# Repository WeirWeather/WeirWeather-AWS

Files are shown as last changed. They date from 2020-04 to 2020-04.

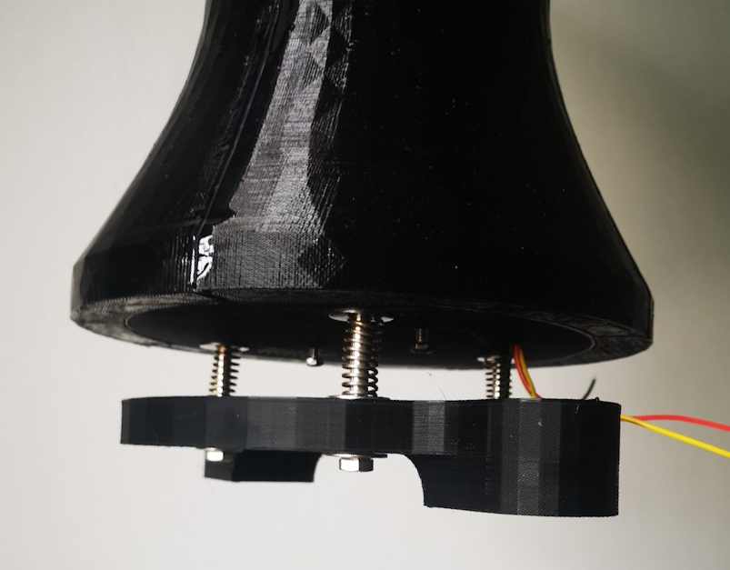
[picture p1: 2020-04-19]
hardware/Rain Gauge/Photos/Support.png

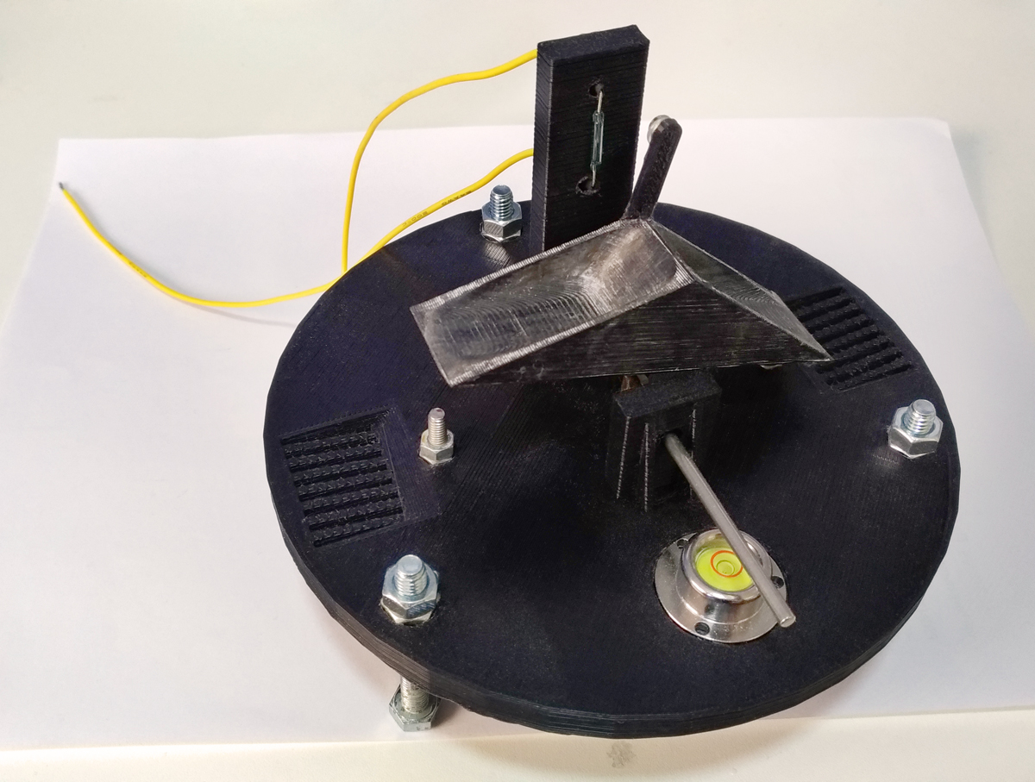
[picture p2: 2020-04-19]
hardware/Rain Gauge/Photos/Prototype Base.jpg

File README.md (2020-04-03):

# WeirWeather

This repository is for the WeirWeather Automatic Weather Station project which provides live weather measurements from the James Weir buidling in Glasgow, co-ordinates: [55.862809, -4.245339]. This repository contains all of the software, CAD models, BOMs and EAGLE PCB files required to reproduce the weather station and the website.

This project was completed for a Masters group project at the University of Strathclyde Electrical & Electronic Engineering Department. 

WeirWeather - 

- Callum Brooksby
- Zack North
- Mario Manca
- Alexander Ulrichsen
- Tesfu Gebremedhin

88040462_648263302590816_2950428286498373632_n

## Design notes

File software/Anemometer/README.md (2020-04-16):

# Anemometer Code

## Files
The `Anemometer/` folder contains the corresponding `.ino` file. The code is intended for an ATtiny85 which was programmed through the Arduino IDE.

## Code Key Points
 - Calculate velocity in m/s based on anemometer radius and number of pulses per revolution
 - Average function
 - Debouncing functionality
 - Send data to master on request

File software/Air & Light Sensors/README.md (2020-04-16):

# LDR Code

## Files
The `LDR/` folder contains the corresponding `.ino` file. The code is intended for an ATtiny85 which was programmed through the Arduino IDE.

## Code Key Points
 - Check when the selected pin is high or low (i.e. day or night)
 - Averaging function
 - Send data to master on request

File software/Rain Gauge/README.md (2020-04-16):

# Rain Gauge Code

## Files
The `Rain_Gauge/` folder contains the corresponding `.ino` file. The code is intended for an ATtiny85 which was programmed through the Arduino IDE.

## Code Key Points
 - Read when the reed switch is triggered using an interrupt
 - Debouncing functionality to minimise false readings
 - Evaluate the amount of rain fallen per day in mm
 - Evaluate the rain intensity in mm/h
 - Averaging function for better results
 - Send data to master on request

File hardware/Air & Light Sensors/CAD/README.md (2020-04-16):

# Radiation Shield CAD Files
The radiation shield in this project is an adaptation based on the work of micromet on the designed named "Radiation Shield For Weather Station Temperature/Humidity" which can be found at: https://www.thingiverse.com/thing:1067700

 - `Support.dwg` is the custom support designed to adapted the radiation shield to our AWS
 - `PCB Holder.dwg` is the custom PCB holder designed to sustain the four atmospheric sensors
 - The `STLs/` folder contains the single .stl files as they were 3D-printed

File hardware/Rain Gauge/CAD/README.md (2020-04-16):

# Rain Gauge CAD Files

 - `Rain_Gauge.dwg` is the complete rai gauge CAD drawing, containing base, collector, funnel, PCB enclosure, and support.
 - The `STLs/` folder contains the single .stl files as they were 3D-printed

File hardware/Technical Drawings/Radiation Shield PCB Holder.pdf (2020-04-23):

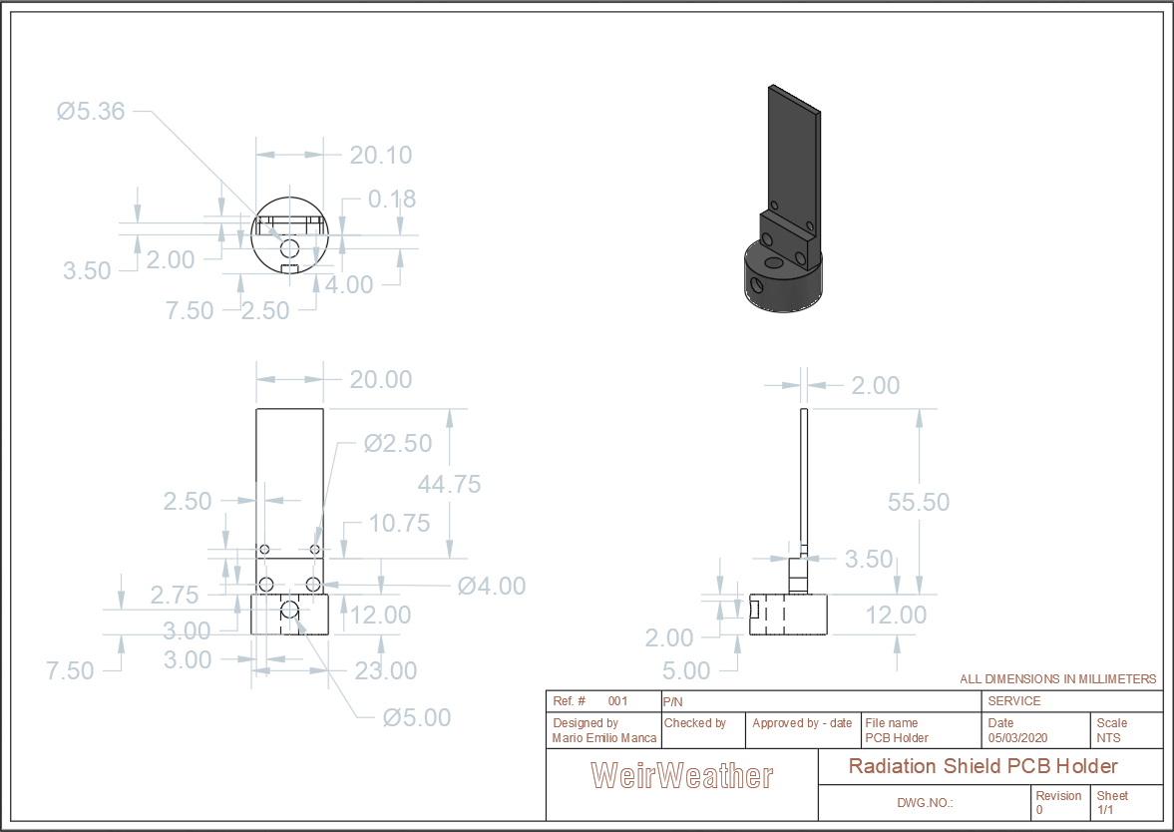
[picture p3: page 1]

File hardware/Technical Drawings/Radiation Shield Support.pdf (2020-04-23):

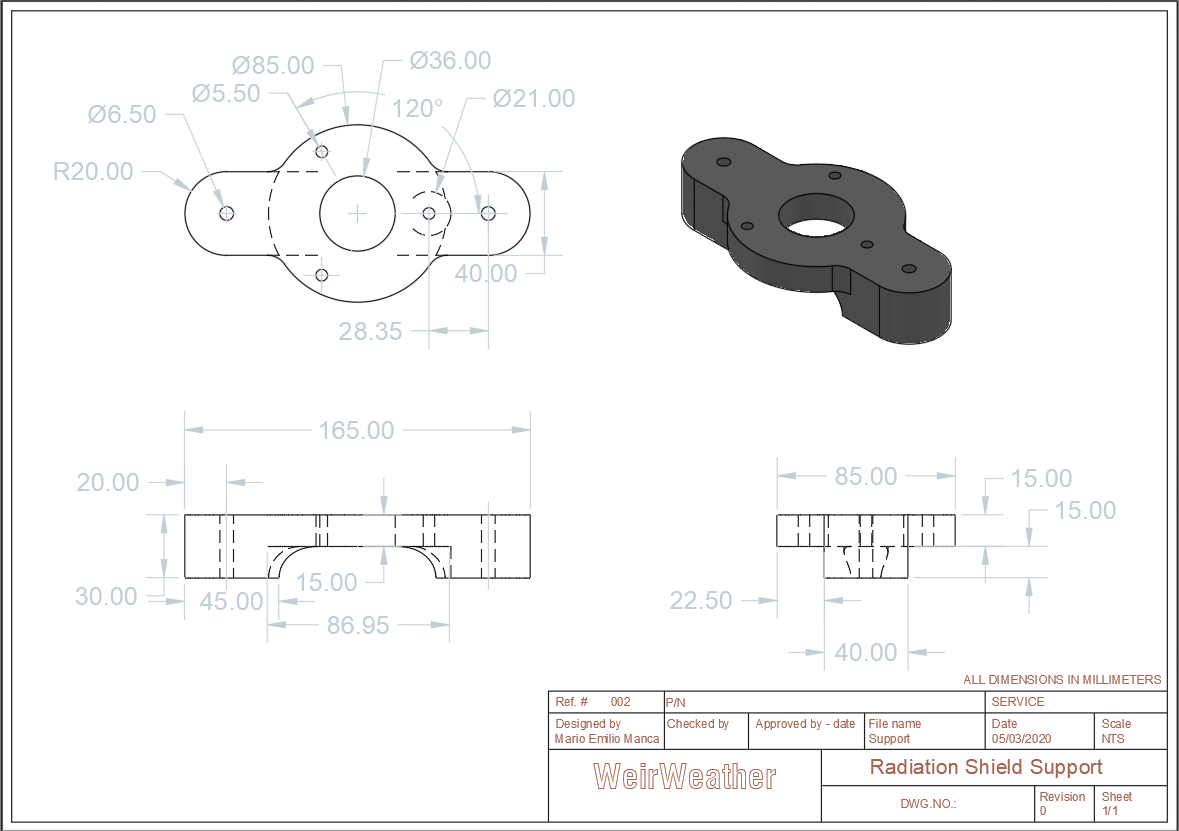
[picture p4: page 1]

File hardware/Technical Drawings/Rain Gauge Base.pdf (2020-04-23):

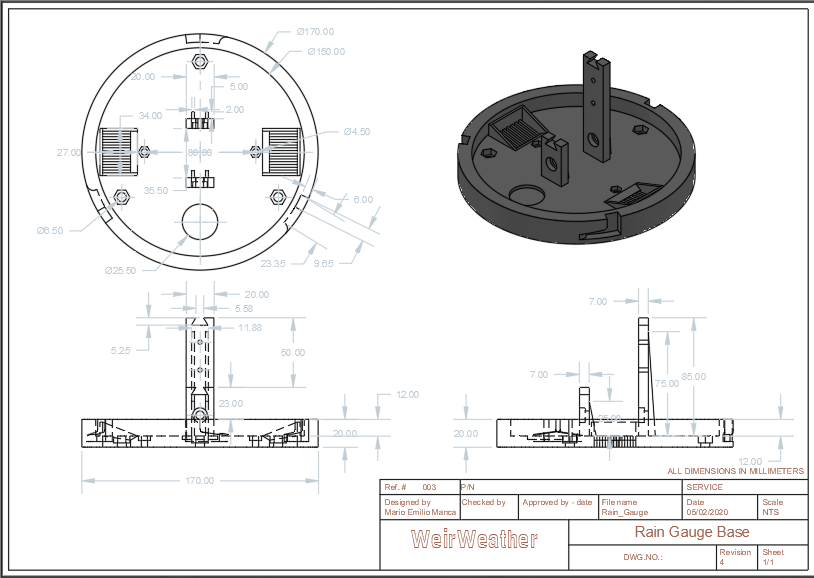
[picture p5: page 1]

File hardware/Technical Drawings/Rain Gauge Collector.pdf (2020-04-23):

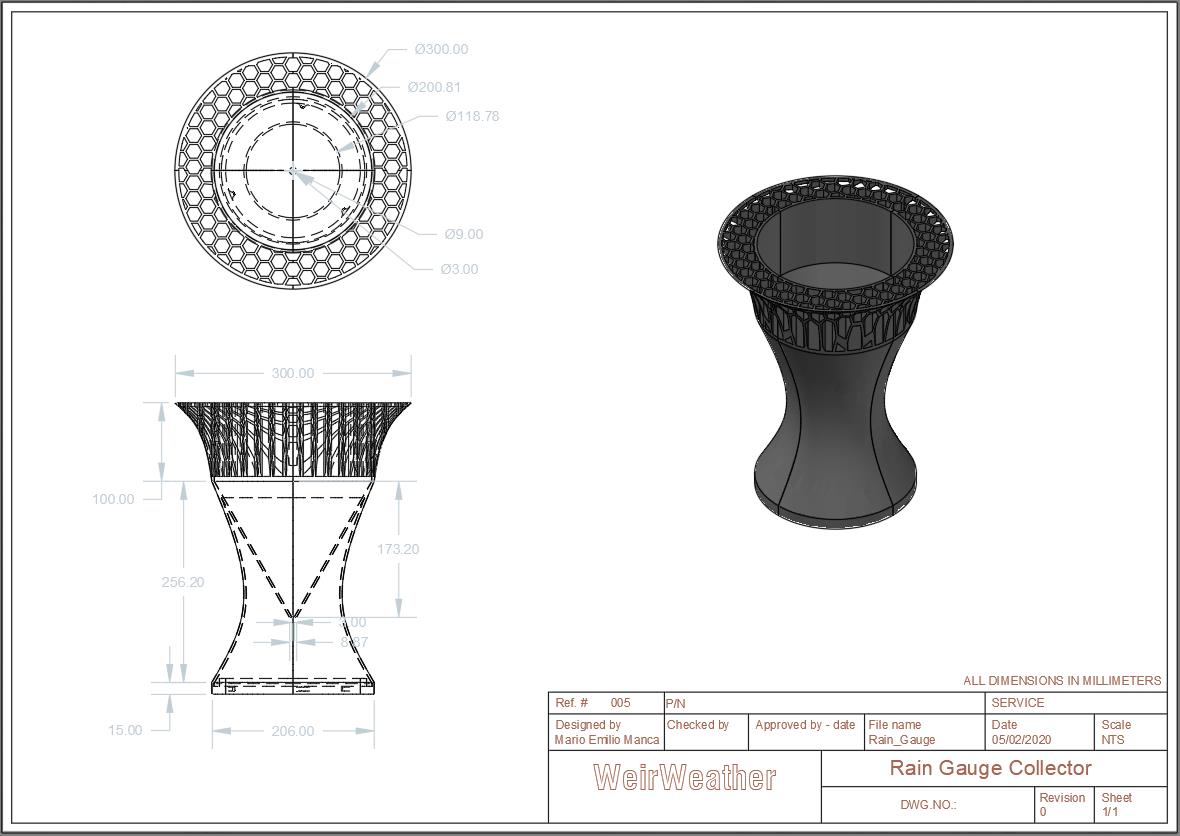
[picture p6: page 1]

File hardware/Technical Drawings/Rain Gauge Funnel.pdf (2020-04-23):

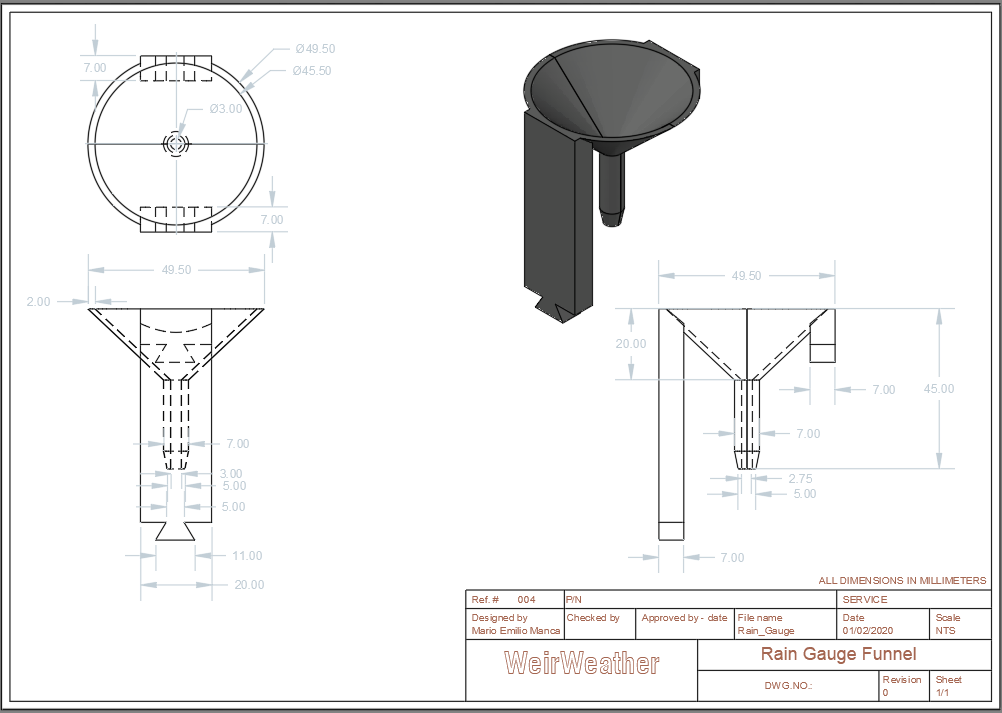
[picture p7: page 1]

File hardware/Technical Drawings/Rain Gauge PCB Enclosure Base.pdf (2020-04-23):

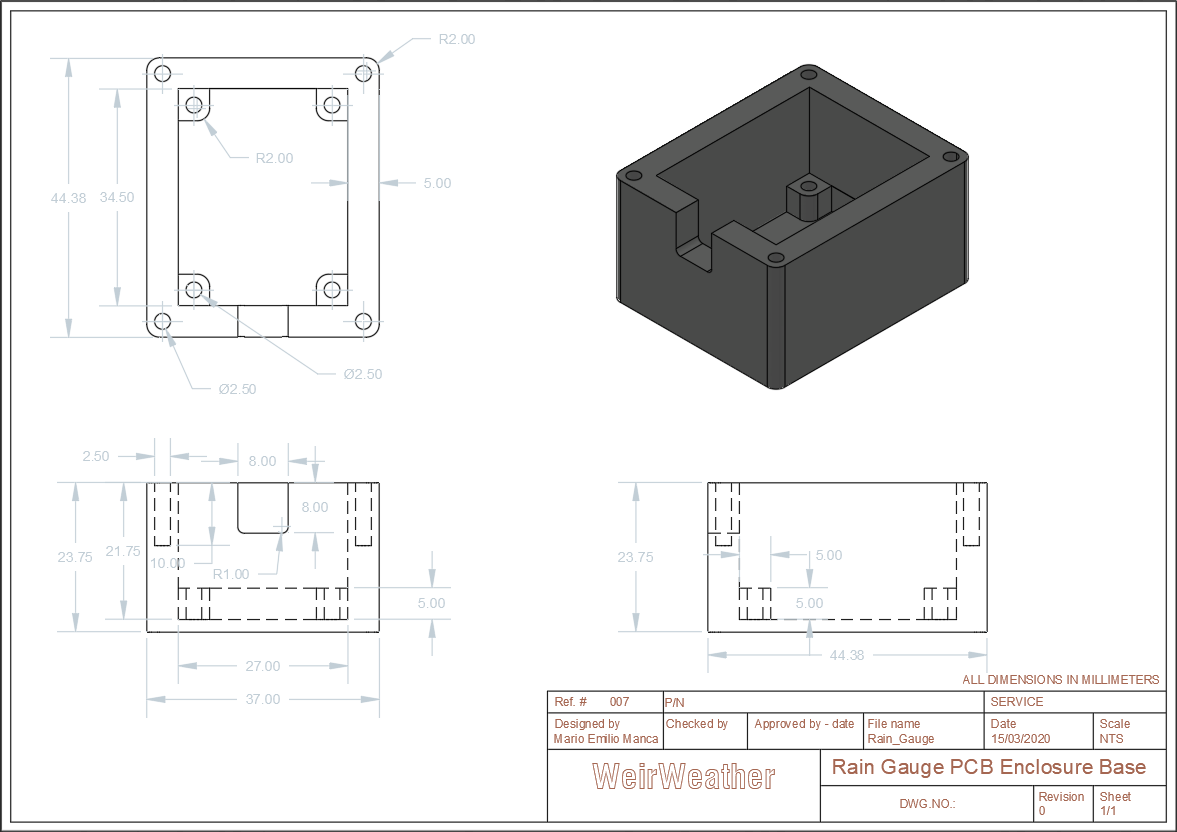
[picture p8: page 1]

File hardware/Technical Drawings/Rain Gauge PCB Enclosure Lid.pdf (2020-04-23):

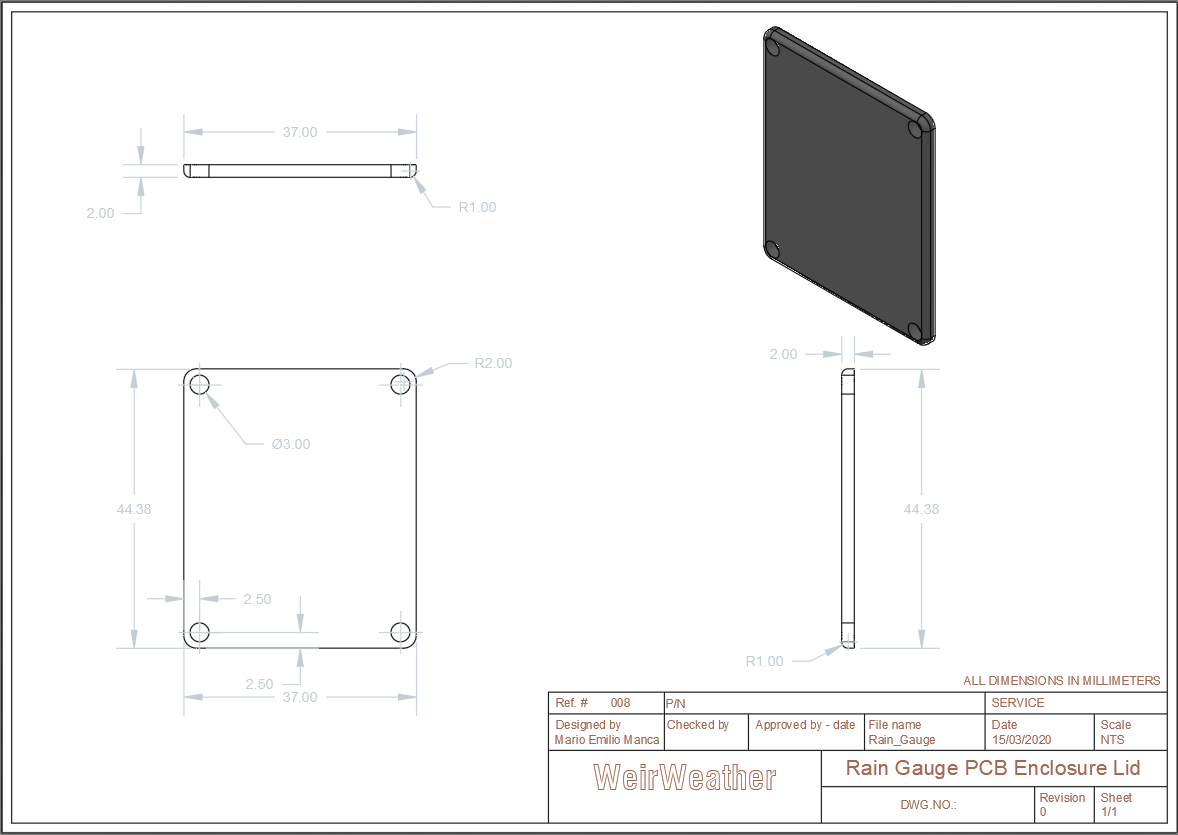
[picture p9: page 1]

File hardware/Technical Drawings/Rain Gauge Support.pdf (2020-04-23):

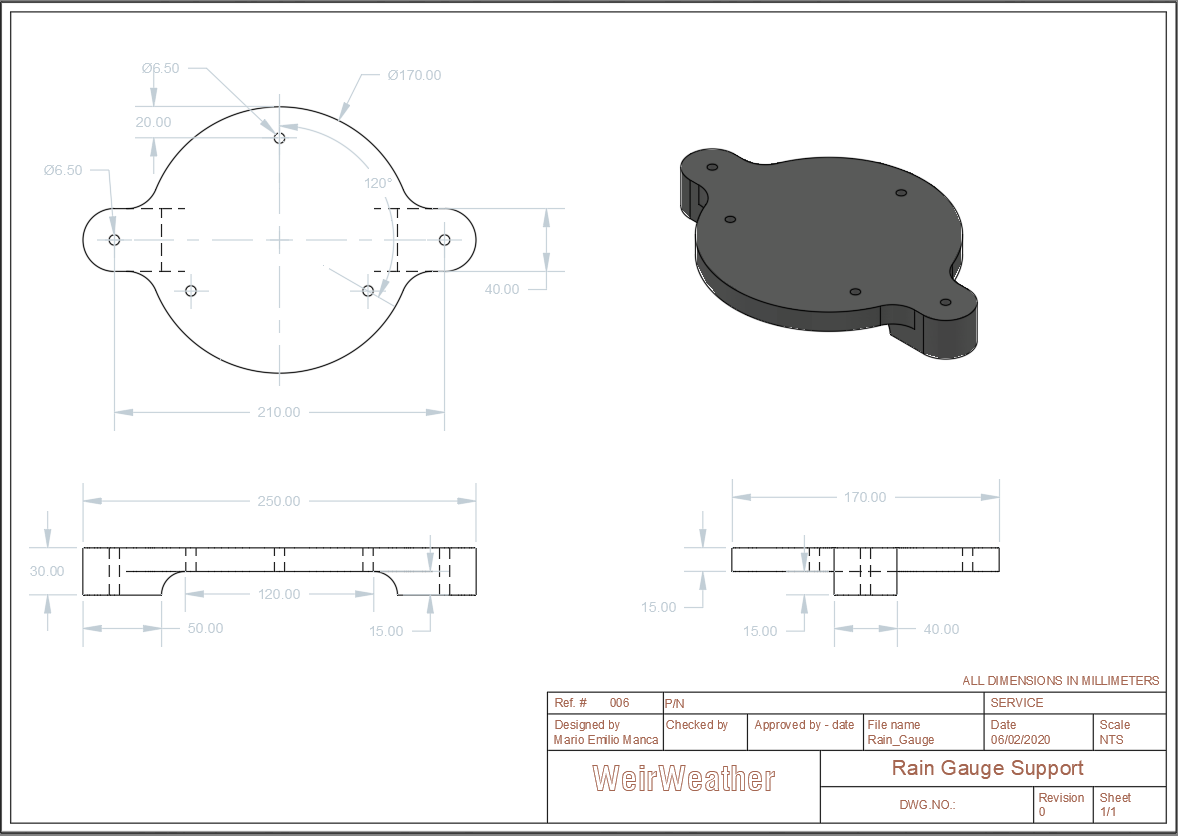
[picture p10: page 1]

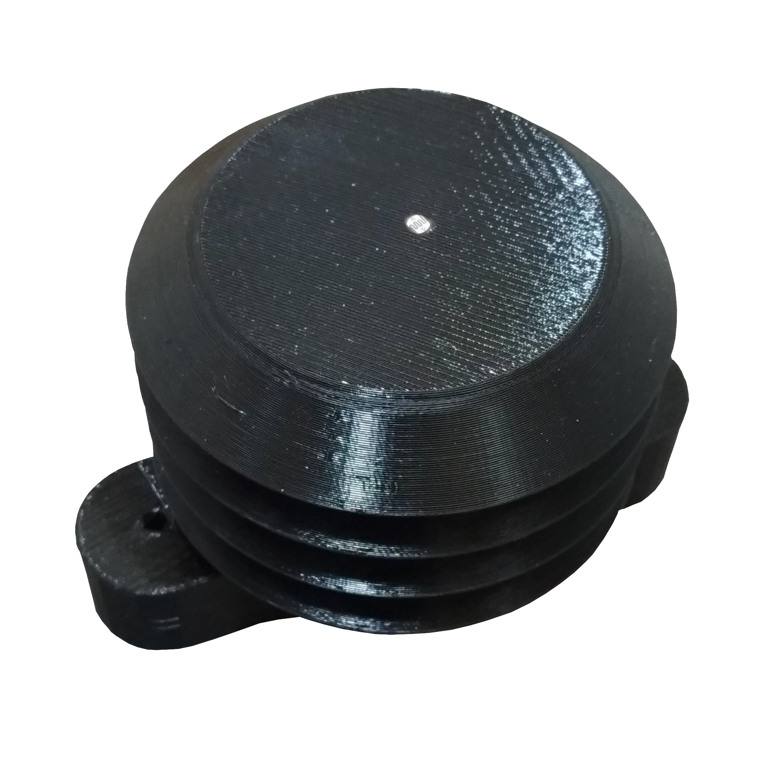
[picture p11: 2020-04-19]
hardware/Air & Light Sensors/Photos/Radiation Shield Top.PNG

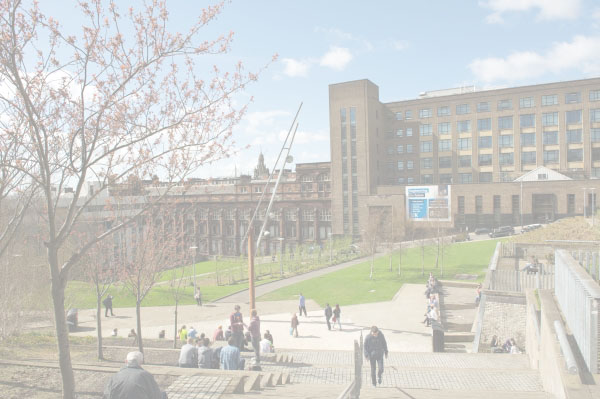
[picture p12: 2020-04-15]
software/Website/Images/james_weir_600x400 copy.jpg

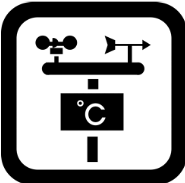
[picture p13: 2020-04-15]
software/Website/Images/Picture 1.png

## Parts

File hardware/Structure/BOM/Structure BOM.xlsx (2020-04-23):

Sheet: BillOfMaterials
WeirWeather Weather Station
 | http://www.vertex42.com/ExcelTemplates/free-timesheet-template.html |  |  |  |  |  |  | © 2012-2014 Vertex42 LLC
 | Assembly Name : | Mechanical Structure and Tethers |  |  |  |  |  | Bill of Materials Template (http://www.vertex42.com/ExcelTemplates/bill-of-materials.html)
 | Assembly Number : | 1
 | Assembly Revision : | 1
 | Approval Date :
 | Part Count : | 124
 | Total Cost : | £155.52
Part # | Part Name | Qty | Supplier | Part No. | Units | Unit Cost | Cost
1 | RS PRO 2m Aluminium Extrusion | 1 | RS | 761-3313 | each | £33.43 | £33.43
2 | RS PRO 1m Aluminium Extrusion | 2 | RS | 761-3319 | each | £16.69 | £33.38
3 | Bag of 10 Endcaps | 1 | RS | 767-5601 | each | £7.20 | £7.20
4 | Bag of 10 M6 T-Slot Nut | 3 | RS | 767-5667 | each | £5.60 | £16.80
5 | RS PRO Bracket Kit | 2 | RS | 767-5698 | each | £10.78 | £21.56
6 | RS PRO Bracket Kit | 1 | RS | 767-5695 | each | £6.32 | £6.32
7 | Solar Panel Lower Mount | 1 | EEE | N/A | each | £0.00 | £0.00
8 | Solar Panel Upper Mount | 1 | EEE | N/A | each | £0.00 | £0.00
9 | 1m 3mm 7x7 Galvanised Steel Wire Rope | 30 | Wire Rope Shop | N/A | each | £0.23 | £6.84
10 | M8 Nyloc Nuts | 10 | Wire Rope Shop | N/A | each | £0.13 | £1.32
11 | M8 Washer | 12 | Wire Rope Shop | N/A | each | £0.06 | £0.72
12 | M8 Stainless Eye Bolt | 2 | Wire Rope Shop | N/A | each | £2.75 | £5.50
13 | 3mm Wire Rope Thimble | 8 | Wire Rope Shop | N/A | each | £0.16 | £1.25
14 | 3mm Wire Rope Cable Grip | 32 | Wire Rope Shop | N/A | each | £0.10 | £3.07
15 | 2x M8 150mm 304 Stainless Steel 13mm Hex Bolt | 1 | Amazon | N/A | each | £6.99 | £6.99
16 | M10 Nyloc Nuts | 2 | Wire Rope Shop | N/A | each | £0.19 | £0.38
17 | M10 Washer | 4 | Wire Rope Shop | N/A | each | £0.08 | £0.34
18 | M8 Nuts | 10 | Wire Rope Shop | N/A | each | £0.08 | £0.84
19 | Steel Wire Rope Cutter | 1 | Wire Rope Shop | N/A | each | £9.59 | £9.59
 | Total | 124 |  |  |  |  | £155.52

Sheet: Revisions
Revision History
 | Assembly Name :
 | Assembly Number :
Revision | Revision Summary | Approval Date

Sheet: Example
Bill of Materials for LEGO® Design
 |  |  | http://www.vertex42.com/ExcelTemplates/free-timesheet-template.html |  |  |  |  |  |  | © 2012-2014 Vertex42 LLC
 |  |  | Assembly Name : | Mini X-Wing™ |  |  | [42] |  |  | Bill of Materials Template (http://www.vertex42.com/ExcelTemplates/bill-of-materials.html)
 |  |  | Assembly Number : | Custom
 |  |  | Assembly Revision :
 |  |  | Approval Date :
 |  |  | Pieces : | 46
 |  |  | Total Cost : | $5.85
Category | Part # | Elem ID | Part Name | Color | Qty | Units | Picture | Unit Cost | Cost
Bricks, Sloping | 50746 | 4504369 | ROOF TILE 1X1X2/3, ABS | 1 - White | 1 | each |  | $0.10 | $0.10
Plates | 3024 | 302401 | PLATE 1X1 | 1 - White | 1 | each |  | $0.10 | $0.10
Plates | 3023 | 302301 | PLATE 1X2 | 1 - White | 2 | each |  | $0.10 | $0.20
Plates | 3023 | 4211398 | PLATE 1X2 | 194 - Medium Stone Grey | 1 | each |  | $0.10 | $0.10
Plates | 3794 | 379401 | PLATE 1X2 W. 1 KNOB | 1 - White | 1 | each |  | $0.10 | $0.10
Plates | 3623 | 362301 | PLATE 1X3 | 1 - White | 1 | each |  | $0.10 | $0.10
Plates | 3623 | 362321 | PLATE 1X3 | 21 - Bright Red | 1 | each |  | $0.10 | $0.10
Plates | 94148 | 302201 | PLATE 2X2 | 1 - White | 1 | each |  | $0.15 | $0.15
Plates, Special | 6141 | 4210633 | PLATE 1X1 ROUND | 199 - Dark Stone Grey | 1 | each |  | $0.10 | $0.10
Plates, Special | 3070 | 307021 | FLAT TILE 1X1 | 21 - Bright Red | 4 | each |  | $0.10 | $0.40
Plates, Special | 2412 | 241201 | RADIATOR GRILLE 1X2 | 1 - White | 1 | each |  | $0.10 | $0.10
Plates, Special | 6019 | 4538353 | PLATE 1X1 W/HOLDER VERTICAL | 1 - White | 4 | each |  | $0.15 | $0.60
Plates, Special | 2431 | 4558168 | FLAT TILE 1X4 | 1 - White | 1 | each |  | $0.20 | $0.20
Plates, Special | 63868 | 4535737 | PLATE 2X1 W/HOLDER,VERTICAL | 1 - White | 4 | each |  | $0.15 | $0.60
Plates, Special | 2540 | 4211632 | PLATE 1X2 W. STICK | 194 - Medium Stone Grey | 4 | each |  | $0.15 | $0.60
Plates, Special | 3176 | 4225733 | COUPLING PLATE 2X2 | 199 - Dark Stone Grey | 1 | each |  | $0.20 | $0.20
Bricks, Special | 49668 | 4224793 | PLATE 1X1 W/TOOTH | 5 - Brick Yellow | 1 | each |  | $0.10 | $0.10
Technic | 32123 | 4211573 | 1/2 BUSH | 194 - Medium Stone Grey | 4 | each |  | $0.10 | $0.40
Technic | 6590 | 4211622 | BUSH FOR CROSS AXLE | 194 - Medium Stone Grey | 8 | each |  | $0.15 | $1.20
Accessories | 3957 | 4211473 | STICK/AERIAL | 194 - Medium Stone Grey | 4 | each |  | $0.10 | $0.40
 |  |  | Total |  | 46 |  |  |  | $5.85

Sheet: ©
Bill of Materials Template
By Vertex42.com
http://www.vertex42.com/ExcelTemplates/bill-of-materials.html
© 2012-2014 Vertex42 LLC
This spreadsheet, including all worksheets and associated content is considered a copyrighted work under the United States and other copyright laws.
Do not submit copies or modifications of this template to any website or online template gallery.
Please review the following license agreement to learn how you may or may not use this template. Thank you.
See License Agreement (http://www.vertex42.com/licensing/EULA_privateuse.html)
http://www.vertex42.com/licensing/EULA_privateuse.html
Do not delete this worksheet. If necessary, you may hide it by right-clicking on the tab and selecting Hide.

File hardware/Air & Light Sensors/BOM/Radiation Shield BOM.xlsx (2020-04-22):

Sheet: BillOfMaterials
WeirWeather Weather Station
 | http://www.vertex42.com/ExcelTemplates/free-timesheet-template.html |  |  |  |  |  |  | © 2012-2014 Vertex42 LLC
 | Assembly Name : | Radiation Shield |  |  |  |  |  | Bill of Materials Template (http://www.vertex42.com/ExcelTemplates/bill-of-materials.html)
 | Assembly Number : | 1
 | Assembly Revision : | 1
 | Approval Date :
 | Part Count : | 32.8
 | Total Cost : | £34.57
Part # | Part Name | Qty | Supplier | Part No. | Units | Unit Cost | Cost
1 | TMP117 | 1 | MOUSER | 595-TMP117AIYBGR | each | £5.96 | £5.96
2 | 1 KΩ resistor | 2 | RS | 125-1190 | each | £0.01 | £0.03
3 | 100 nF capacitor | 6 | RS | 698-3324 | each | £0.05 | £0.30
4 | 10 KΩ resistor | 7 | RS | 432-450 | each | £0.01 | £0.07
5 | DPS310 | 1 | FARNELL | 2709842 | each | £1.72 | £1.72
6 | SHT35 | 1 | MOUSER | 403-SHT35-DIS-F | each | £8.24 | £8.24
7 | ATtiny85 | 1 | RS | 133-1672 | each | £1.15 | £1.15
8 | 16 MHz crystal | 1 | RS | 814-9440 | each | £0.17 | £0.17
9 | 18 pF capacitor | 2 | RS | 648-0935 | each | £0.04 | £0.08
10 | 10 KΩ potentiometer | 1 | RS | 743-2350 | each | £0.50 | £0.50
11 | LDR | 1 | FARNELL | 7482280 | each | £1.89 | £1.89
12 | PCB manufacturing | 1 | JLCPCB | N/A | each | £3.06 | £3.06
13 | PETG [Kg] | 0.3 | 3DGBIRE | N/A | each | £32.00 | £9.60
14 | M5 threaded road | 0.5 | eBay | N/A | each | £6.37 | £3.19
15 | M5 nut | 3 | eBay | N/A | each | £0.18 | £0.54
16 | M5 bolt | 1 | eBay | N/A | each | £0.18 | £0.18
17 | M5 washer | 3 | eBay | N/A | each | £0.10 | £0.30
 | Total | 32.8 |  |  |  |  | £36.97

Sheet: Revisions
Revision History
 | Assembly Name :
 | Assembly Number :
Revision | Revision Summary | Approval Date

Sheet: Example
Bill of Materials for LEGO® Design
 |  |  | http://www.vertex42.com/ExcelTemplates/free-timesheet-template.html |  |  |  |  |  |  | © 2012-2014 Vertex42 LLC
 |  |  | Assembly Name : | Mini X-Wing™ |  |  | [42] |  |  | Bill of Materials Template (http://www.vertex42.com/ExcelTemplates/bill-of-materials.html)
 |  |  | Assembly Number : | Custom
 |  |  | Assembly Revision :
 |  |  | Approval Date :
 |  |  | Pieces : | 46
 |  |  | Total Cost : | $5.85
Category | Part # | Elem ID | Part Name | Color | Qty | Units | Picture | Unit Cost | Cost
Bricks, Sloping | 50746 | 4504369 | ROOF TILE 1X1X2/3, ABS | 1 - White | 1 | each |  | $0.10 | $0.10
Plates | 3024 | 302401 | PLATE 1X1 | 1 - White | 1 | each |  | $0.10 | $0.10
Plates | 3023 | 302301 | PLATE 1X2 | 1 - White | 2 | each |  | $0.10 | $0.20
Plates | 3023 | 4211398 | PLATE 1X2 | 194 - Medium Stone Grey | 1 | each |  | $0.10 | $0.10
Plates | 3794 | 379401 | PLATE 1X2 W. 1 KNOB | 1 - White | 1 | each |  | $0.10 | $0.10
Plates | 3623 | 362301 | PLATE 1X3 | 1 - White | 1 | each |  | $0.10 | $0.10
Plates | 3623 | 362321 | PLATE 1X3 | 21 - Bright Red | 1 | each |  | $0.10 | $0.10
Plates | 94148 | 302201 | PLATE 2X2 | 1 - White | 1 | each |  | $0.15 | $0.15
Plates, Special | 6141 | 4210633 | PLATE 1X1 ROUND | 199 - Dark Stone Grey | 1 | each |  | $0.10 | $0.10
Plates, Special | 3070 | 307021 | FLAT TILE 1X1 | 21 - Bright Red | 4 | each |  | $0.10 | $0.40
Plates, Special | 2412 | 241201 | RADIATOR GRILLE 1X2 | 1 - White | 1 | each |  | $0.10 | $0.10
Plates, Special | 6019 | 4538353 | PLATE 1X1 W/HOLDER VERTICAL | 1 - White | 4 | each |  | $0.15 | $0.60
Plates, Special | 2431 | 4558168 | FLAT TILE 1X4 | 1 - White | 1 | each |  | $0.20 | $0.20
Plates, Special | 63868 | 4535737 | PLATE 2X1 W/HOLDER,VERTICAL | 1 - White | 4 | each |  | $0.15 | $0.60
Plates, Special | 2540 | 4211632 | PLATE 1X2 W. STICK | 194 - Medium Stone Grey | 4 | each |  | $0.15 | $0.60
Plates, Special | 3176 | 4225733 | COUPLING PLATE 2X2 | 199 - Dark Stone Grey | 1 | each |  | $0.20 | $0.20
Bricks, Special | 49668 | 4224793 | PLATE 1X1 W/TOOTH | 5 - Brick Yellow | 1 | each |  | $0.10 | $0.10
Technic | 32123 | 4211573 | 1/2 BUSH | 194 - Medium Stone Grey | 4 | each |  | $0.10 | $0.40
Technic | 6590 | 4211622 | BUSH FOR CROSS AXLE | 194 - Medium Stone Grey | 8 | each |  | $0.15 | $1.20
Accessories | 3957 | 4211473 | STICK/AERIAL | 194 - Medium Stone Grey | 4 | each |  | $0.10 | $0.40
 |  |  | Total |  | 46 |  |  |  | $5.85

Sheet: ©
Bill of Materials Template
By Vertex42.com
http://www.vertex42.com/ExcelTemplates/bill-of-materials.html
© 2012-2014 Vertex42 LLC
This spreadsheet, including all worksheets and associated content is considered a copyrighted work under the United States and other copyright laws.
Do not submit copies or modifications of this template to any website or online template gallery.
Please review the following license agreement to learn how you may or may not use this template. Thank you.
See License Agreement (http://www.vertex42.com/licensing/EULA_privateuse.html)
http://www.vertex42.com/licensing/EULA_privateuse.html
Do not delete this worksheet. If necessary, you may hide it by right-clicking on the tab and selecting Hide.

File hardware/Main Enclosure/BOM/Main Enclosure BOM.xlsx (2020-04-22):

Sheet: BillOfMaterials
WeirWeather Weather Station
 | http://www.vertex42.com/ExcelTemplates/free-timesheet-template.html |  |  |  |  |  |  | © 2012-2014 Vertex42 LLC
 | Assembly Name : | Main Enclosure and Solar Panel Assembly |  |  |  |  |  | Bill of Materials Template (http://www.vertex42.com/ExcelTemplates/bill-of-materials.html)
 | Assembly Number : | 1
 | Assembly Revision : | 1
 | Approval Date :
 | Part Count : | 26
 | Total Cost : | £230.04
Part # | Part Name | Qty | Supplier | Part No. | Units | Unit Cost | Cost
1 | IP67 SMA to AMC4 (u.FL) 150mm Adaptor Cable | 1 | MOUSER | 523-095-902-502-150 | each | £11.55 | £11.55
2 | L712AS IP68 2.5mm DC Power Jack | 1 | MOUSER | 502-L712AS | each | £3.99 | £3.99
3 | 761KS15 IP68 2.5mm DC Power Plug | 1 | MOUSER | 502-761KS15 | each | £4.10 | £4.10
4 | Ansmann 3.7V 5.2Ah Lithium Ion Rechargable Battery Pack | 1 | RS | 776-0863 | each | £25.94 | £25.94
5 | AVX 10k Thermistor | 1 | RS | 697-4578 | each | £2.03 | £2.03
6 | Adafruit VERTER Buck-Boost | 1 | ThePiHut | ADA2190 | each | £9.00 | £9.00
7 | Adafruit Solar Charger | 1 | ThePiHut | ADA390 | each | £16.00 | £16.00
8 | RS PRO Panel Mount, 9 Pin Waterproof D-sub | 1 | RS | 122-3035 | each | £11.88 | £11.88
9 | JST PHR Female Connector Housing 2mm | 10 | RS | 820-1466 | each | £0.09 | £0.88
10 | JST SPH-002T-P0.5S Contact | 20 | Farnell | 1671245 | each | £0.02 | £0.48
11 | DELTA7B/X/SMAM/S/S/11 GSM/GPRS SMA Antenna | 1 | RS | 124-8685 | each | £8.53 | £8.53
12 | SIM800L GSM Module | 1 | Amazon | N/A | each | £3.64 | £3.64
13 | EE 300014713 PAYG 4G Sim with 6 GB Data | 1 | Amazon | N/A | each | £19.59 | £19.59
14 | Adafruit 6W Solar Panel | 1 | ThePiHut | ADA1525 | each | £54.50 | £54.50
15 | RS PRO Die Cast Aluminium Enclosure, IP66 | 1 | RS | 479-9984 | each | £27.66 | £27.66
16 | Arduino Pro Mini 328 - 3.3V/8MHz | 1 | Hobbytronics | N/A | each | £8.94 | £8.94
17 | 10 Way JST XH 2.5mm Cable Assembly | 1 | eBay | N/A | each | £0.50 | £0.50
18 | 20 Way 2.54mm PCB Headers | 5 | eBay | N/A | each | £0.20 | £1.00
19 | Microchip TC1014 Voltage Regulator | 1 | RS | 738-6219 | each | £0.26 | £0.26
20 | Master PCB | 1 | JLCPCB | N/A | each | £3.06 | £3.06
21 | DS3231 Real Time Clock | 1 | eBay | N/A | each | £2.95 | £2.95
22 | 470 uF capacitor | 1 | RS | 648-0727 | each | £0.08 | £0.08
23 | 1uF tantalum capacitor | 2 | RS | 548-0158 | each | £0.58 | £1.16
24 | TSR 1-2433 Voltage Regulator | 1 | RS | 666-4360 | each | £4.72 | £4.72
25 | PETg for Enclosure Inserts (kg) | 0.2 | 3DGBIRE | N/A | each | £32.00 | £6.40
26 | RS PRO DC Power Plug | 1 | RS | 487-858 | each | £1.20 | £1.20
 | Total | 58.2 |  |  |  |  | £230.04

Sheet: Revisions
Revision History
 | Assembly Name :
 | Assembly Number :
Revision | Revision Summary | Approval Date

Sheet: Example
Bill of Materials for LEGO® Design
 |  |  | http://www.vertex42.com/ExcelTemplates/free-timesheet-template.html |  |  |  |  |  |  | © 2012-2014 Vertex42 LLC
 |  |  | Assembly Name : | Mini X-Wing™ |  |  | [42] |  |  | Bill of Materials Template (http://www.vertex42.com/ExcelTemplates/bill-of-materials.html)
 |  |  | Assembly Number : | Custom
 |  |  | Assembly Revision :
 |  |  | Approval Date :
 |  |  | Pieces : | 46
 |  |  | Total Cost : | $5.85
Category | Part # | Elem ID | Part Name | Color | Qty | Units | Picture | Unit Cost | Cost
Bricks, Sloping | 50746 | 4504369 | ROOF TILE 1X1X2/3, ABS | 1 - White | 1 | each |  | $0.10 | $0.10
Plates | 3024 | 302401 | PLATE 1X1 | 1 - White | 1 | each |  | $0.10 | $0.10
Plates | 3023 | 302301 | PLATE 1X2 | 1 - White | 2 | each |  | $0.10 | $0.20
Plates | 3023 | 4211398 | PLATE 1X2 | 194 - Medium Stone Grey | 1 | each |  | $0.10 | $0.10
Plates | 3794 | 379401 | PLATE 1X2 W. 1 KNOB | 1 - White | 1 | each |  | $0.10 | $0.10
Plates | 3623 | 362301 | PLATE 1X3 | 1 - White | 1 | each |  | $0.10 | $0.10
Plates | 3623 | 362321 | PLATE 1X3 | 21 - Bright Red | 1 | each |  | $0.10 | $0.10
Plates | 94148 | 302201 | PLATE 2X2 | 1 - White | 1 | each |  | $0.15 | $0.15
Plates, Special | 6141 | 4210633 | PLATE 1X1 ROUND | 199 - Dark Stone Grey | 1 | each |  | $0.10 | $0.10
Plates, Special | 3070 | 307021 | FLAT TILE 1X1 | 21 - Bright Red | 4 | each |  | $0.10 | $0.40
Plates, Special | 2412 | 241201 | RADIATOR GRILLE 1X2 | 1 - White | 1 | each |  | $0.10 | $0.10
Plates, Special | 6019 | 4538353 | PLATE 1X1 W/HOLDER VERTICAL | 1 - White | 4 | each |  | $0.15 | $0.60
Plates, Special | 2431 | 4558168 | FLAT TILE 1X4 | 1 - White | 1 | each |  | $0.20 | $0.20
Plates, Special | 63868 | 4535737 | PLATE 2X1 W/HOLDER,VERTICAL | 1 - White | 4 | each |  | $0.15 | $0.60
Plates, Special | 2540 | 4211632 | PLATE 1X2 W. STICK | 194 - Medium Stone Grey | 4 | each |  | $0.15 | $0.60
Plates, Special | 3176 | 4225733 | COUPLING PLATE 2X2 | 199 - Dark Stone Grey | 1 | each |  | $0.20 | $0.20
Bricks, Special | 49668 | 4224793 | PLATE 1X1 W/TOOTH | 5 - Brick Yellow | 1 | each |  | $0.10 | $0.10
Technic | 32123 | 4211573 | 1/2 BUSH | 194 - Medium Stone Grey | 4 | each |  | $0.10 | $0.40
Technic | 6590 | 4211622 | BUSH FOR CROSS AXLE | 194 - Medium Stone Grey | 8 | each |  | $0.15 | $1.20
Accessories | 3957 | 4211473 | STICK/AERIAL | 194 - Medium Stone Grey | 4 | each |  | $0.10 | $0.40
 |  |  | Total |  | 46 |  |  |  | $5.85

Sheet: ©
Bill of Materials Template
By Vertex42.com
http://www.vertex42.com/ExcelTemplates/bill-of-materials.html
© 2012-2014 Vertex42 LLC
This spreadsheet, including all worksheets and associated content is considered a copyrighted work under the United States and other copyright laws.
Do not submit copies or modifications of this template to any website or online template gallery.
Please review the following license agreement to learn how you may or may not use this template. Thank you.
See License Agreement (http://www.vertex42.com/licensing/EULA_privateuse.html)
http://www.vertex42.com/licensing/EULA_privateuse.html
Do not delete this worksheet. If necessary, you may hide it by right-clicking on the tab and selecting Hide.

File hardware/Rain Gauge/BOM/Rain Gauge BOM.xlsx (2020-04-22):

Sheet: BillOfMaterials
WeirWeather Weather Station
 | http://www.vertex42.com/ExcelTemplates/free-timesheet-template.html |  |  |  |  |  |  | © 2012-2014 Vertex42 LLC
 | Assembly Name : | Rain Gauge |  |  |  |  |  | Bill of Materials Template (http://www.vertex42.com/ExcelTemplates/bill-of-materials.html)
 | Assembly Number : | 1
 | Assembly Revision : | 1
 | Approval Date :
 | Part Count : | 38.5
 | Total Cost : | £57.84
Part # | Part Name | Qty | Supplier | Part No. | Units | Unit Cost | Cost
1 | ATtiny85 | 1 | RS | 133-1672 | each | £1.15 | £1.15
2 | 16 MHz Crystal | 1 | RS | 814-9440 | each | £0.17 | £0.17
3 | 18 pF Capacitor | 2 | RS | 648-0935 | each | £0.04 | £0.09
4 | 10 KΩ resistor | 2 | RS | 432-450 | each | £0.01 | £0.01
5 | 100 nF capacitor | 1 | RS | 698-3324 | each | £0.05 | £0.05
6 | Reed switch | 1 | RS | 905-8875 | each | £0.23 | £0.23
7 | Magnet | 1 | FARNELL | 1800037 | each | £0.52 | £0.52
8 | PCB manufacturing | 1 | JCLPCB | N/A | each | £1.53 | £1.53
9 | Ball bearing | 3 | RS | 618-9884 | each | £1.84 | £5.52
10 | 3 mm stainless steel rod | 1 | eBay | N/A | each | £1.79 | £1.79
11 | PETg [Kg] | 1.5 | 3DGBIRE | N/A | each | £32.00 | £48.00
12 | Stainless steel M4 nut | 2 | eBay | N/A | each | £0.18 | £0.36
13 | Stainless steel M6 nut | 3 | eBay | N/A | each | £0.19 | £0.57
14 | Stainless steel M4 25 mm bolt | 2 | eBay | N/A | each | £0.18 | £0.36
15 | Stainless steel M6 60 mm bolt | 3 | eBay | N/A | each | £0.55 | £1.65
14 | Stainless steel M6 20 mm whasher | 9 | eBay | N/A | each | £0.10 | £0.90
15 | Stainless steel 25 mm spring | 3 | eBay | N/A | each | £0.99 | £2.97
16 | Spirti level | 1 | eBay | N/A | each | £3.97 | £3.97
 | Total | 38.5 |  |  |  |  | £69.83

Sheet: Revisions
Revision History
 | Assembly Name :
 | Assembly Number :
Revision | Revision Summary | Approval Date

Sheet: Example
Bill of Materials for LEGO® Design
 |  |  | http://www.vertex42.com/ExcelTemplates/free-timesheet-template.html |  |  |  |  |  |  | © 2012-2014 Vertex42 LLC
 |  |  | Assembly Name : | Mini X-Wing™ |  |  | [42] |  |  | Bill of Materials Template (http://www.vertex42.com/ExcelTemplates/bill-of-materials.html)
 |  |  | Assembly Number : | Custom
 |  |  | Assembly Revision :
 |  |  | Approval Date :
 |  |  | Pieces : | 46
 |  |  | Total Cost : | $5.85
Category | Part # | Elem ID | Part Name | Color | Qty | Units | Picture | Unit Cost | Cost
Bricks, Sloping | 50746 | 4504369 | ROOF TILE 1X1X2/3, ABS | 1 - White | 1 | each |  | $0.10 | $0.10
Plates | 3024 | 302401 | PLATE 1X1 | 1 - White | 1 | each |  | $0.10 | $0.10
Plates | 3023 | 302301 | PLATE 1X2 | 1 - White | 2 | each |  | $0.10 | $0.20
Plates | 3023 | 4211398 | PLATE 1X2 | 194 - Medium Stone Grey | 1 | each |  | $0.10 | $0.10
Plates | 3794 | 379401 | PLATE 1X2 W. 1 KNOB | 1 - White | 1 | each |  | $0.10 | $0.10
Plates | 3623 | 362301 | PLATE 1X3 | 1 - White | 1 | each |  | $0.10 | $0.10
Plates | 3623 | 362321 | PLATE 1X3 | 21 - Bright Red | 1 | each |  | $0.10 | $0.10
Plates | 94148 | 302201 | PLATE 2X2 | 1 - White | 1 | each |  | $0.15 | $0.15
Plates, Special | 6141 | 4210633 | PLATE 1X1 ROUND | 199 - Dark Stone Grey | 1 | each |  | $0.10 | $0.10
Plates, Special | 3070 | 307021 | FLAT TILE 1X1 | 21 - Bright Red | 4 | each |  | $0.10 | $0.40
Plates, Special | 2412 | 241201 | RADIATOR GRILLE 1X2 | 1 - White | 1 | each |  | $0.10 | $0.10
Plates, Special | 6019 | 4538353 | PLATE 1X1 W/HOLDER VERTICAL | 1 - White | 4 | each |  | $0.15 | $0.60
Plates, Special | 2431 | 4558168 | FLAT TILE 1X4 | 1 - White | 1 | each |  | $0.20 | $0.20
Plates, Special | 63868 | 4535737 | PLATE 2X1 W/HOLDER,VERTICAL | 1 - White | 4 | each |  | $0.15 | $0.60
Plates, Special | 2540 | 4211632 | PLATE 1X2 W. STICK | 194 - Medium Stone Grey | 4 | each |  | $0.15 | $0.60
Plates, Special | 3176 | 4225733 | COUPLING PLATE 2X2 | 199 - Dark Stone Grey | 1 | each |  | $0.20 | $0.20
Bricks, Special | 49668 | 4224793 | PLATE 1X1 W/TOOTH | 5 - Brick Yellow | 1 | each |  | $0.10 | $0.10
Technic | 32123 | 4211573 | 1/2 BUSH | 194 - Medium Stone Grey | 4 | each |  | $0.10 | $0.40
Technic | 6590 | 4211622 | BUSH FOR CROSS AXLE | 194 - Medium Stone Grey | 8 | each |  | $0.15 | $1.20
Accessories | 3957 | 4211473 | STICK/AERIAL | 194 - Medium Stone Grey | 4 | each |  | $0.10 | $0.40
 |  |  | Total |  | 46 |  |  |  | $5.85

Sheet: ©
Bill of Materials Template
By Vertex42.com
http://www.vertex42.com/ExcelTemplates/bill-of-materials.html
© 2012-2014 Vertex42 LLC
This spreadsheet, including all worksheets and associated content is considered a copyrighted work under the United States and other copyright laws.
Do not submit copies or modifications of this template to any website or online template gallery.
Please review the following license agreement to learn how you may or may not use this template. Thank you.
See License Agreement (http://www.vertex42.com/licensing/EULA_privateuse.html)
http://www.vertex42.com/licensing/EULA_privateuse.html
Do not delete this worksheet. If necessary, you may hide it by right-clicking on the tab and selecting Hide.

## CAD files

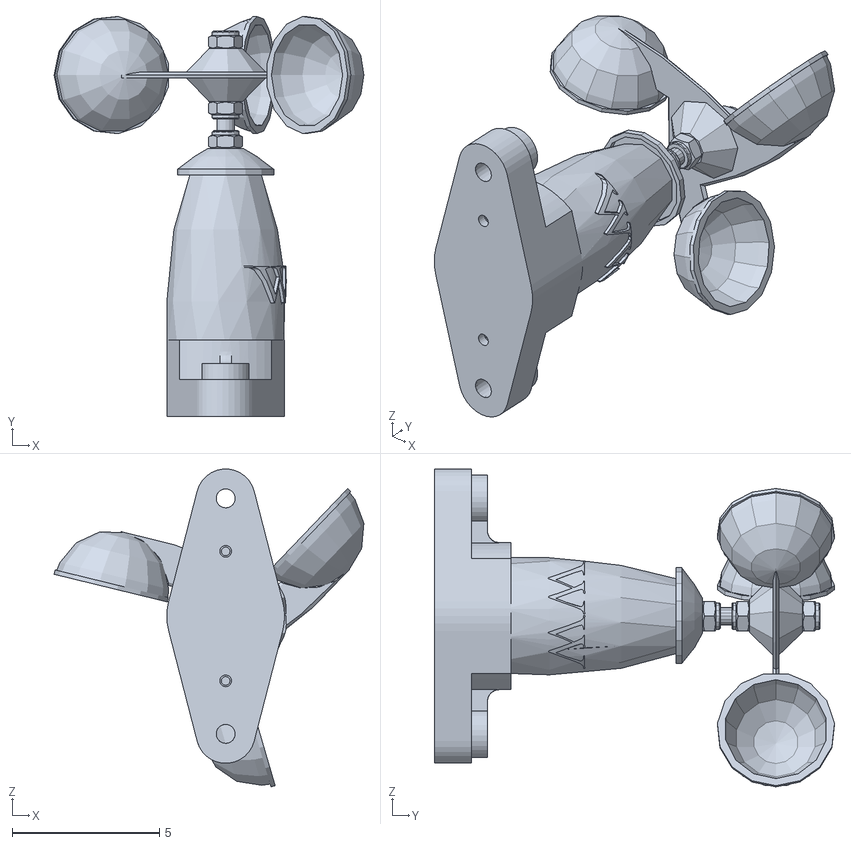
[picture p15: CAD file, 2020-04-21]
hardware/Complete CAD Assembly/3D Print/Anemometer Assy.stl
10.5 x 13.6 x 10.8

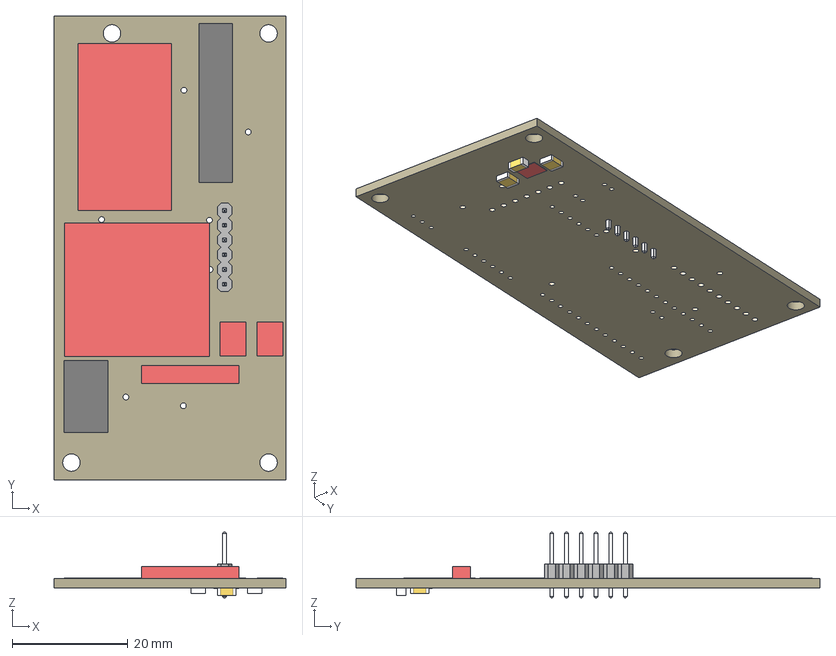
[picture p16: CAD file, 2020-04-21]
hardware/Complete CAD Assembly/PCB CAD/MainBoardV4.step
40.0 x 80.0 x 11.3 mm
Board
SIM800LMODULE
MA07-1
JST-XH-10-PIN-ROUND-PAD
1X06
JST-PH2 x 2
ABK-PRO-MINI
TSR_1-2433
TC1014-3.3VCT713
470 pF
1 uF x 2

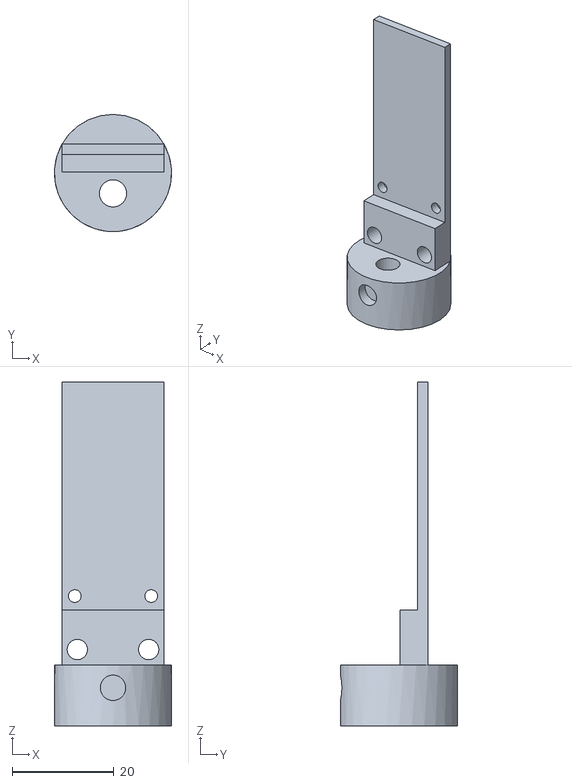
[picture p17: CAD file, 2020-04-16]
hardware/Air & Light Sensors/CAD/STLs/PCB Holder.stl
23.0 x 23.0 x 67.5

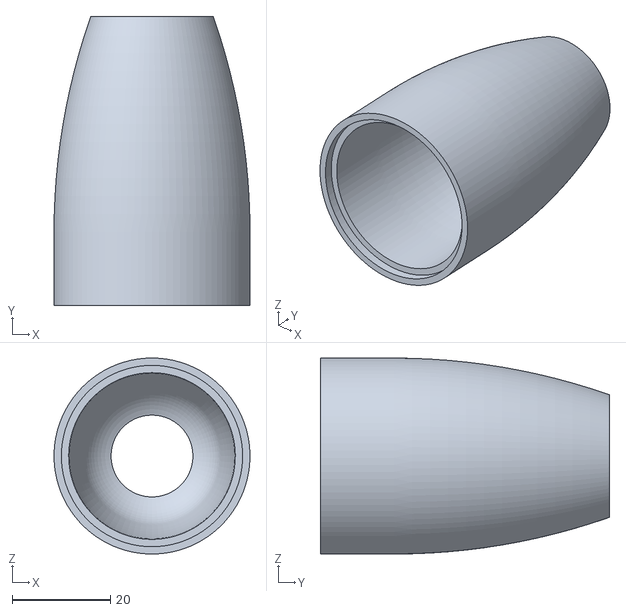
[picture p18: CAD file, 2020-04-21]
hardware/Complete CAD Assembly/3D Print/Lid.stl
40.0 x 59.0 x 40.0

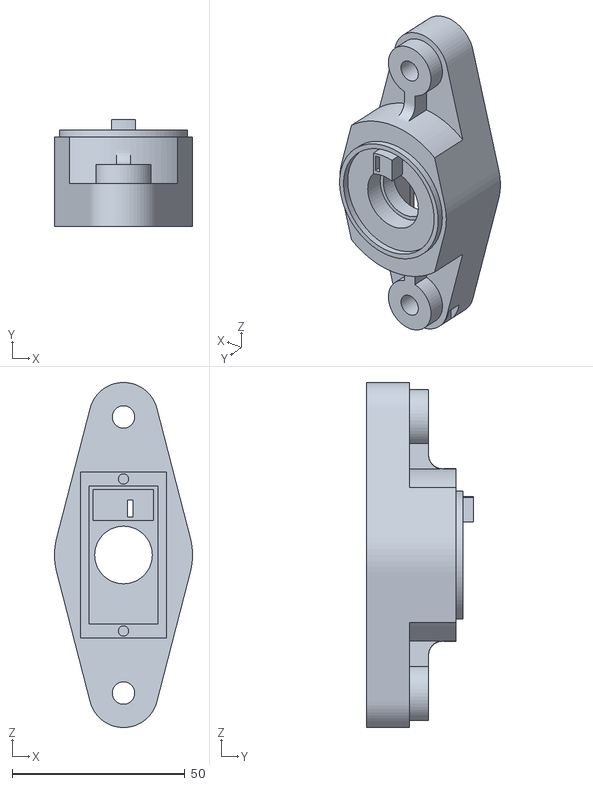
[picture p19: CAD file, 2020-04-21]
hardware/Complete CAD Assembly/anenometer/Base-v1.stl
40.0 x 31.0 x 100.0

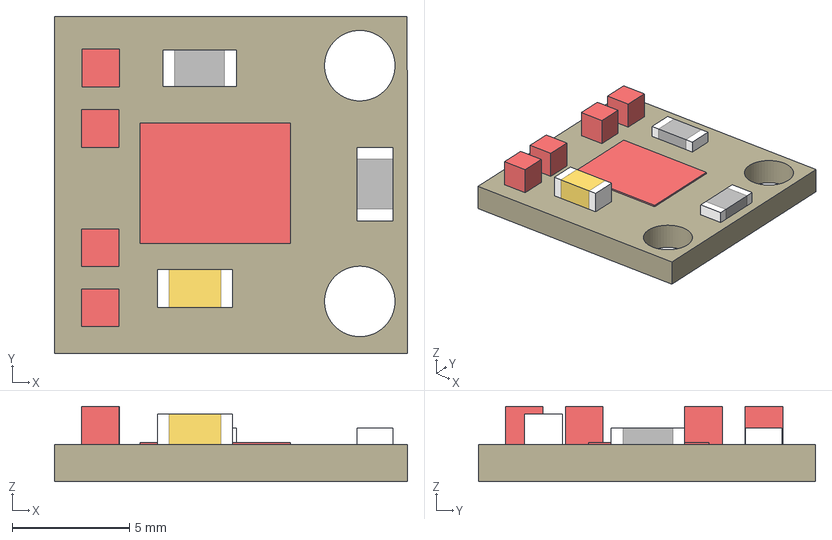
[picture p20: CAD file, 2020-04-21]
hardware/Complete CAD Assembly/PCB CAD/windvane_v2.step
15.0 x 14.3 x 3.20 mm
Board
100n
1,6/0,8 x 4
AS5600
4.7k x 2

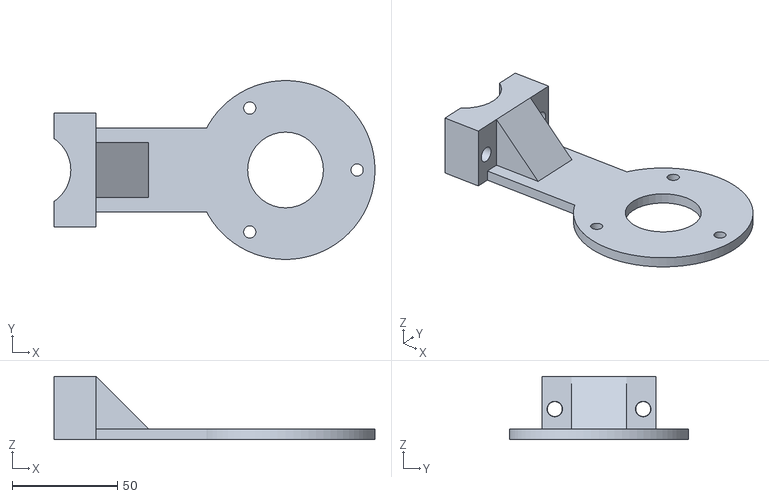
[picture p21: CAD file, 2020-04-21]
hardware/Complete CAD Assembly/Radiation Sheild/Rad_Shd_Vert_mount_V1.stl
152.5 x 85.0 x 30.0

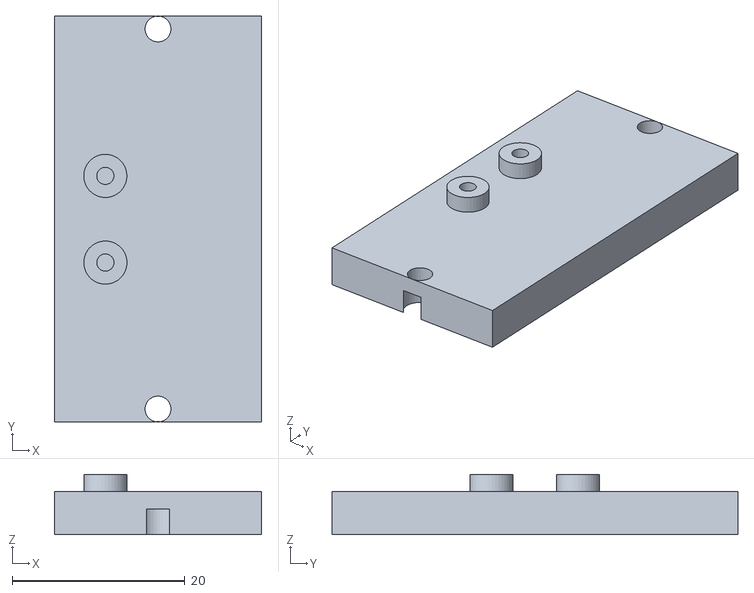
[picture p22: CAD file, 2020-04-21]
hardware/Complete CAD Assembly/Wind Vane/Bottom.stl
24.0 x 47.0 x 7.00

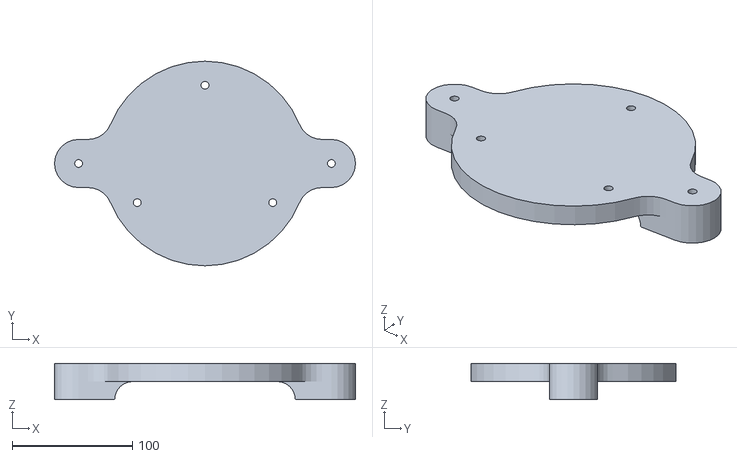
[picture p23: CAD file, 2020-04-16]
hardware/Rain Gauge/CAD/STLs/Support.stl
250.0 x 170.0 x 30.0

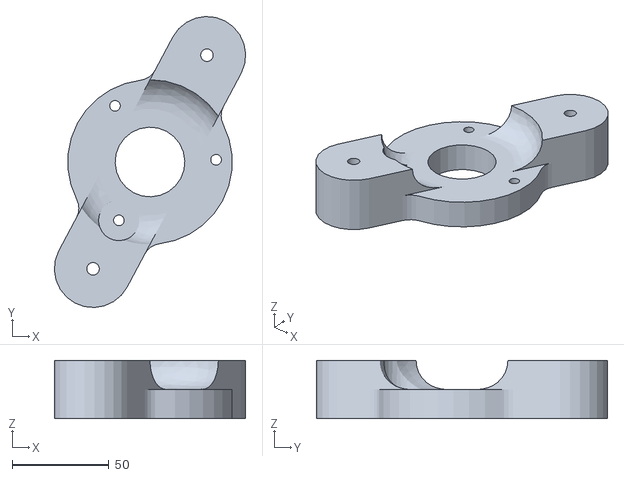
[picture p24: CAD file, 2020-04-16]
hardware/Air & Light Sensors/CAD/STLs/Support.stl
98.8 x 150.3 x 30.0

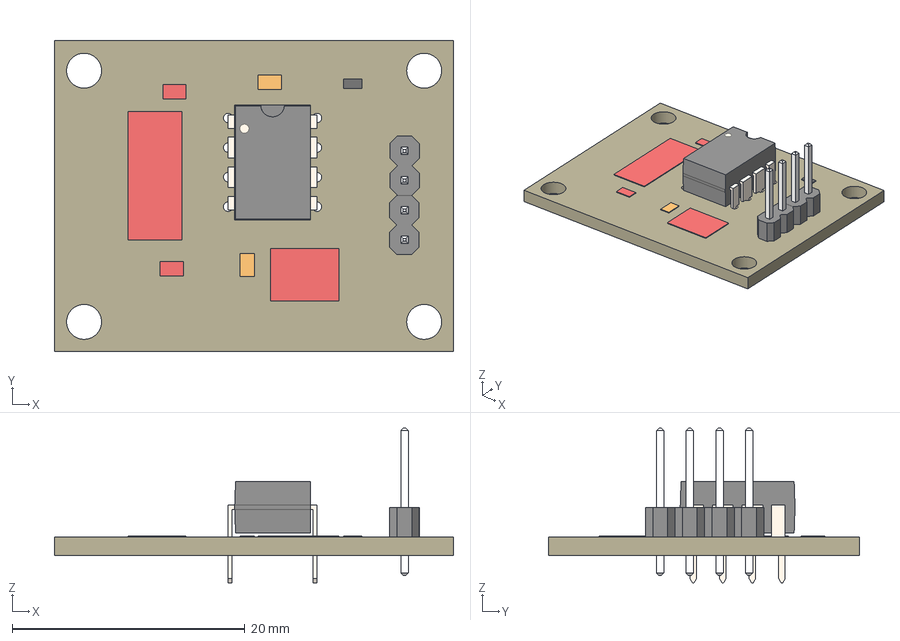
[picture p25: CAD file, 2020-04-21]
hardware/Complete CAD Assembly/PCB CAD/Rain_Gauge_PCB_V2.step
34.3 x 26.7 x 13.3 mm
Board
DIL08
QCL16.0000F18B23B
C0805C180J5GACTU x 2
0603YC104KAZ2A
RK73B2ATTD103J x 2
1X02 x 2
JST-PH2

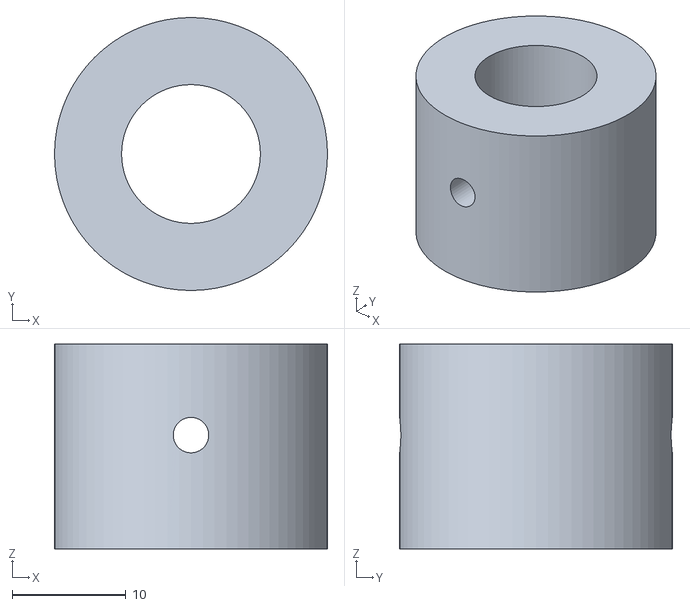
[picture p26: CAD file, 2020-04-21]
hardware/Complete CAD Assembly/Radiation Sheild/HTM2500_mount_V1.stl
24.0 x 24.0 x 18.0

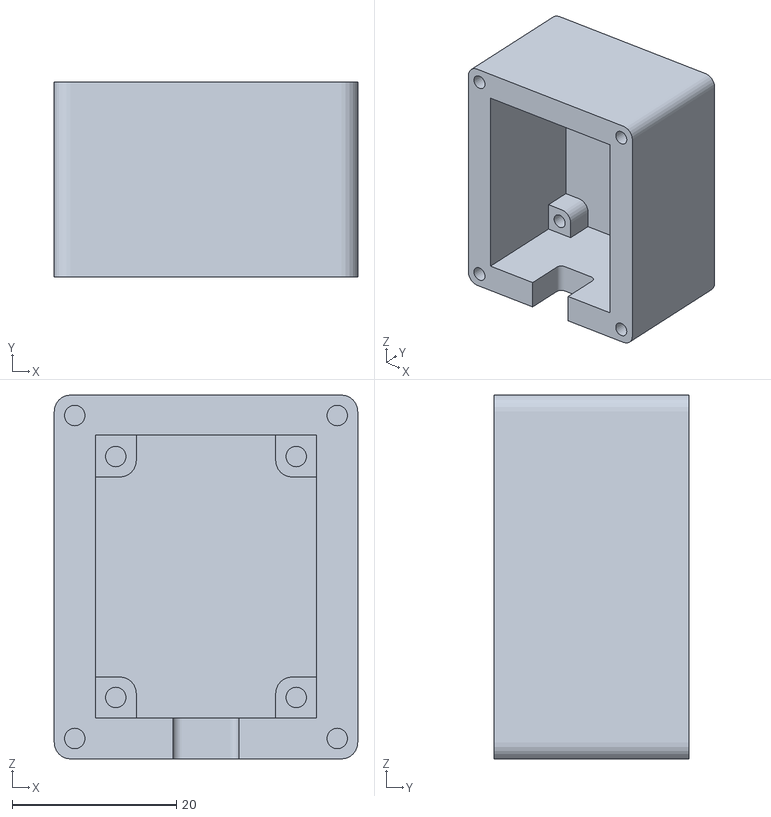
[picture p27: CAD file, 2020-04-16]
hardware/Rain Gauge/CAD/STLs/PCB_Holder.stl
37.0 x 23.8 x 44.4

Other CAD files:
hardware/Complete CAD Assembly/Drawings/Scoops.dwg
hardware/Complete CAD Assembly/Rain Gauge/Base and Collector.dwg
hardware/Rain Gauge/CAD/Rain_Gauge.dwg
hardware/Complete CAD Assembly/Drawings/Body.dwg
hardware/Complete CAD Assembly/Rain Gauge/Bucket.dwg
hardware/Air & Light Sensors/CAD/PCB Holder.dwg
hardware/Air & Light Sensors/CAD/Support.dwg
hardware/Complete CAD Assembly/3D Print/Base.stl
hardware/Complete CAD Assembly/3D Print/Bottom-1.stl
hardware/Complete CAD Assembly/3D Print/Bottom.stl
hardware/Complete CAD Assembly/3D Print/Cap.stl
hardware/Complete CAD Assembly/3D Print/Disk-3.stl
hardware/Complete CAD Assembly/3D Print/Disk-4.stl
hardware/Complete CAD Assembly/3D Print/Lid-V2.stl
hardware/Complete CAD Assembly/3D Print/Scoops.stl
hardware/Complete CAD Assembly/3D Print/Wind Vane Print V2.stl
hardware/Complete CAD Assembly/3D Print/Wind Vane Print.stl
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

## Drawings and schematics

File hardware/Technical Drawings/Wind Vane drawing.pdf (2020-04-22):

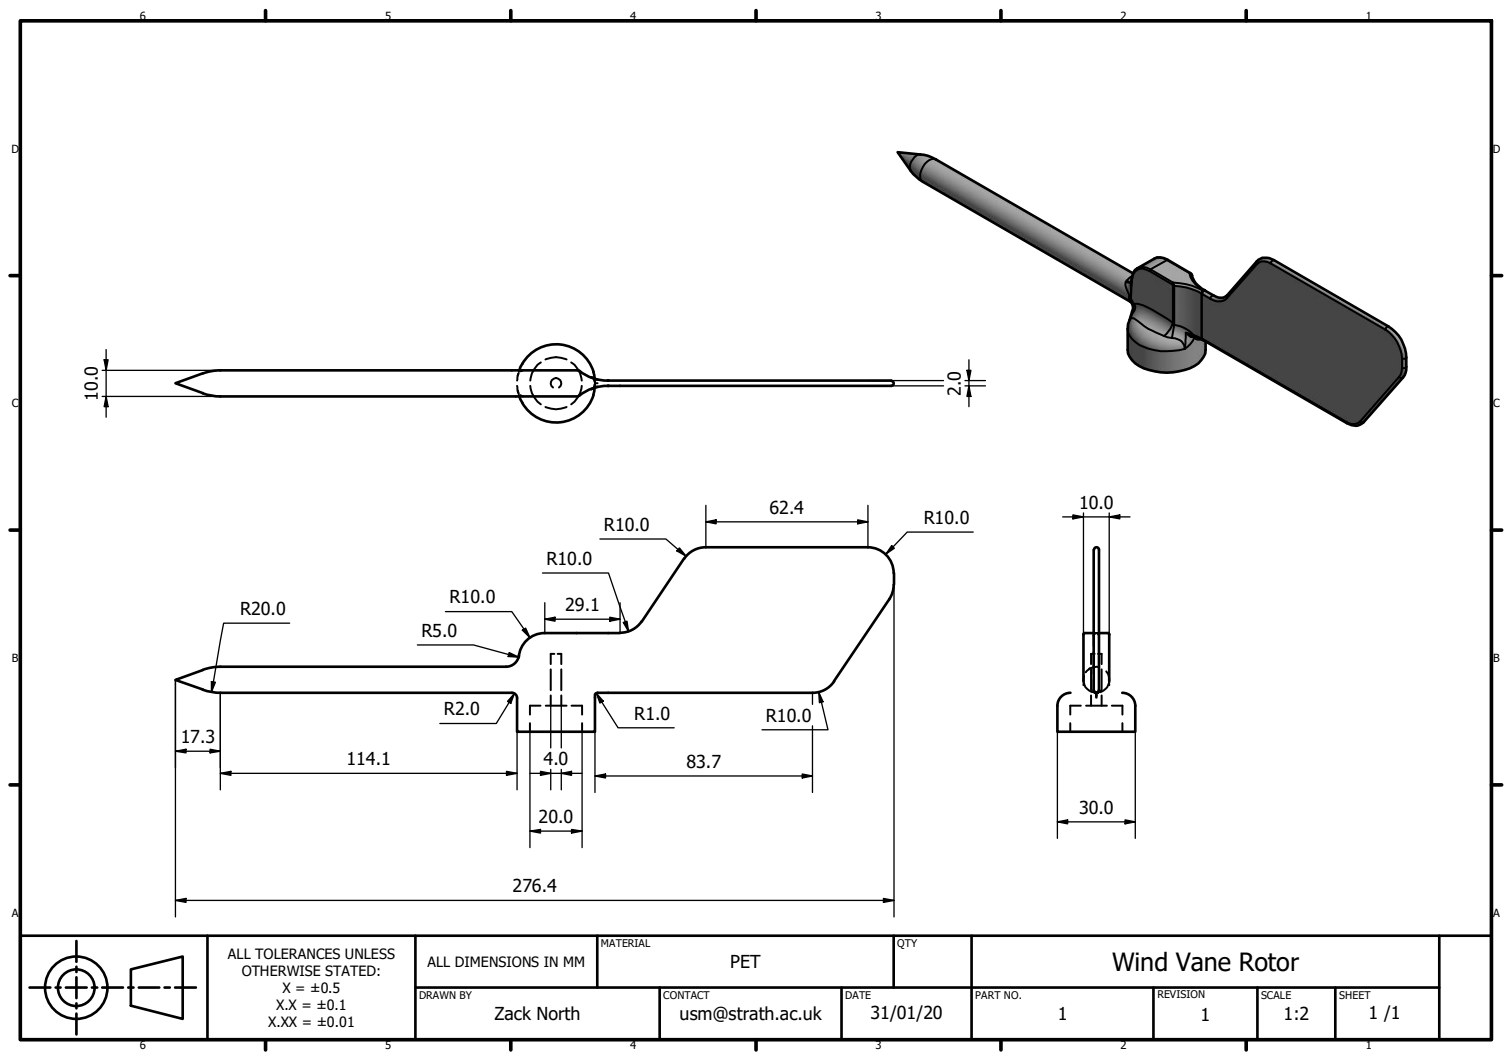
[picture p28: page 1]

ALL TOLERANCES UNLESS OTHERWISE STATED: X = ±0.5 X.X = ±0.1 X.XX = ±0.01 | ALL DIMENSIONS IN MM | MATERIAL PET | QTY | Wind Vane Rotor

DRAWN BY Zack North | CONTACT usm@strath.ac.uk | DATE 31/01/20 | PART NO. 1 | REVISION 1 | SCALE 1:2 | SHEET 1 /1

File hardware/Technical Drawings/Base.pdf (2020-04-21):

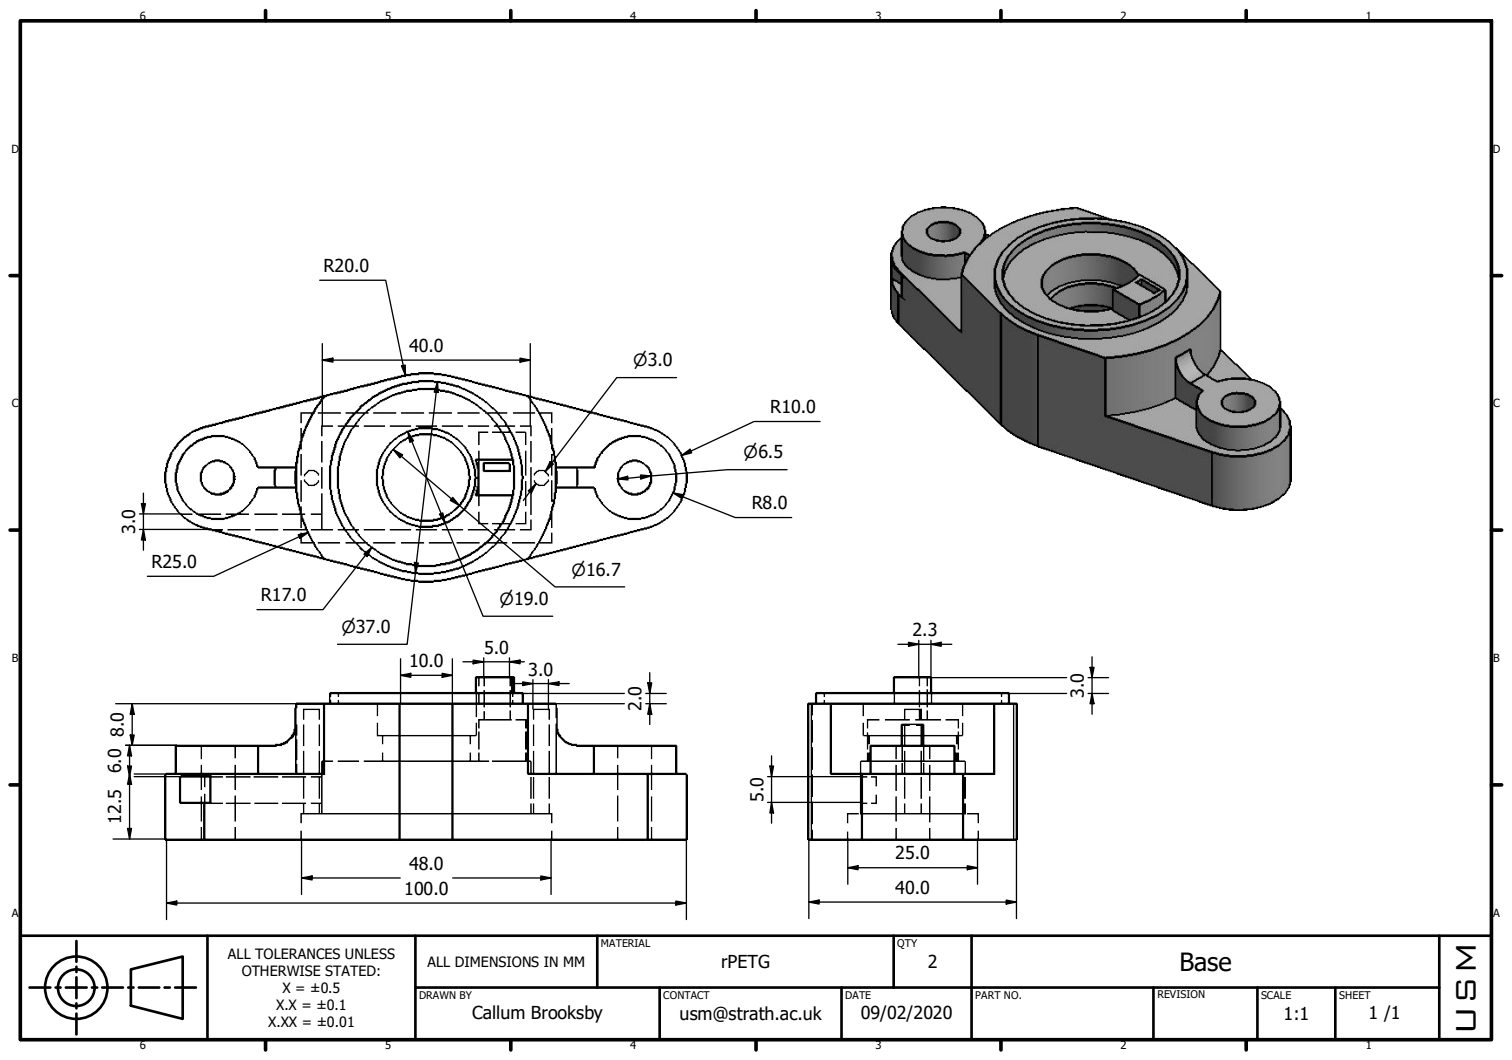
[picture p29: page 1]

ALL TOLERANCES UNLESS OTHERWISE STATED: X = ±0.5 X.X = ±0.1 X.XX = ±0.01 | ALL DIMENSIONS IN MM | MATERIAL rPETG | QTY 2 | Base | M

DRAWN BY Callum Brooksby | CONTACT usm@strath.ac.uk | DATE 09/02/2020 | PART NO. | REVISION | SCALE 1:1 | SHEET 1 /1

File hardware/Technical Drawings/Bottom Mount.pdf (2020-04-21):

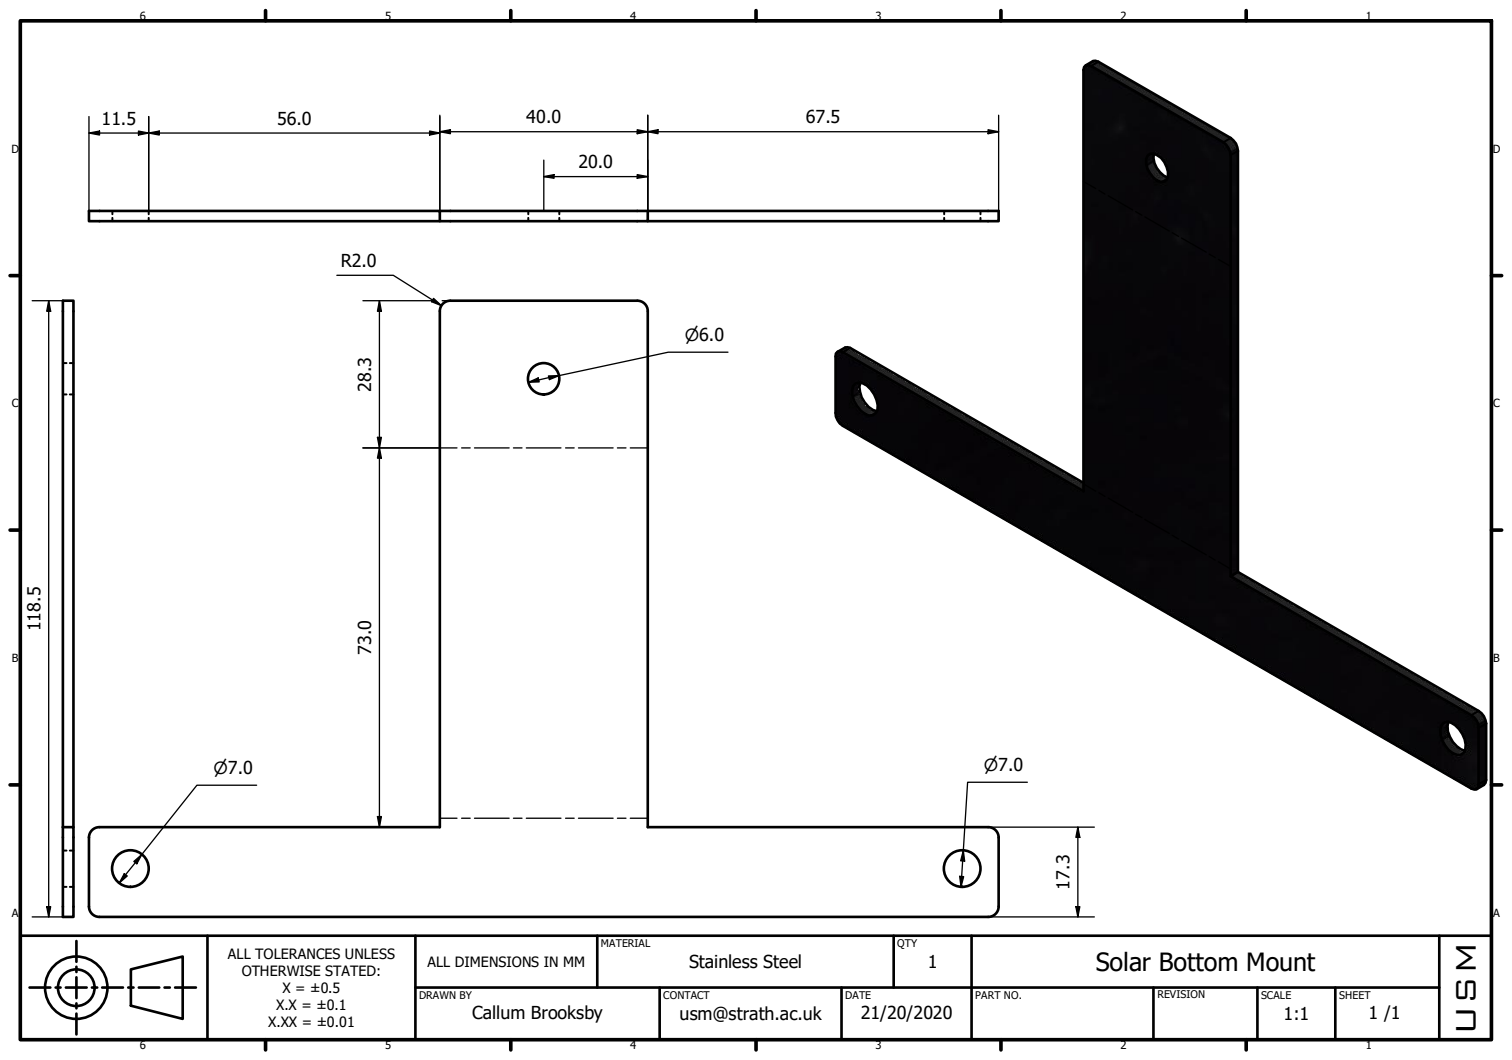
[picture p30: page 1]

ALL TOLERANCES UNLESS OTHERWISE STATED: X = ±0.5 X.X = ±0.1 X.XX = ±0.01 | ALL DIMENSIONS IN MM | MATERIAL Stainless Steel | QTY 1 | Solar Bottom Mount | M

DRAWN BY Callum Brooksby | CONTACT usm@strath.ac.uk | DATE 21/20/2020 | PART NO. | REVISION | SCALE 1:1 | SHEET 1 /1

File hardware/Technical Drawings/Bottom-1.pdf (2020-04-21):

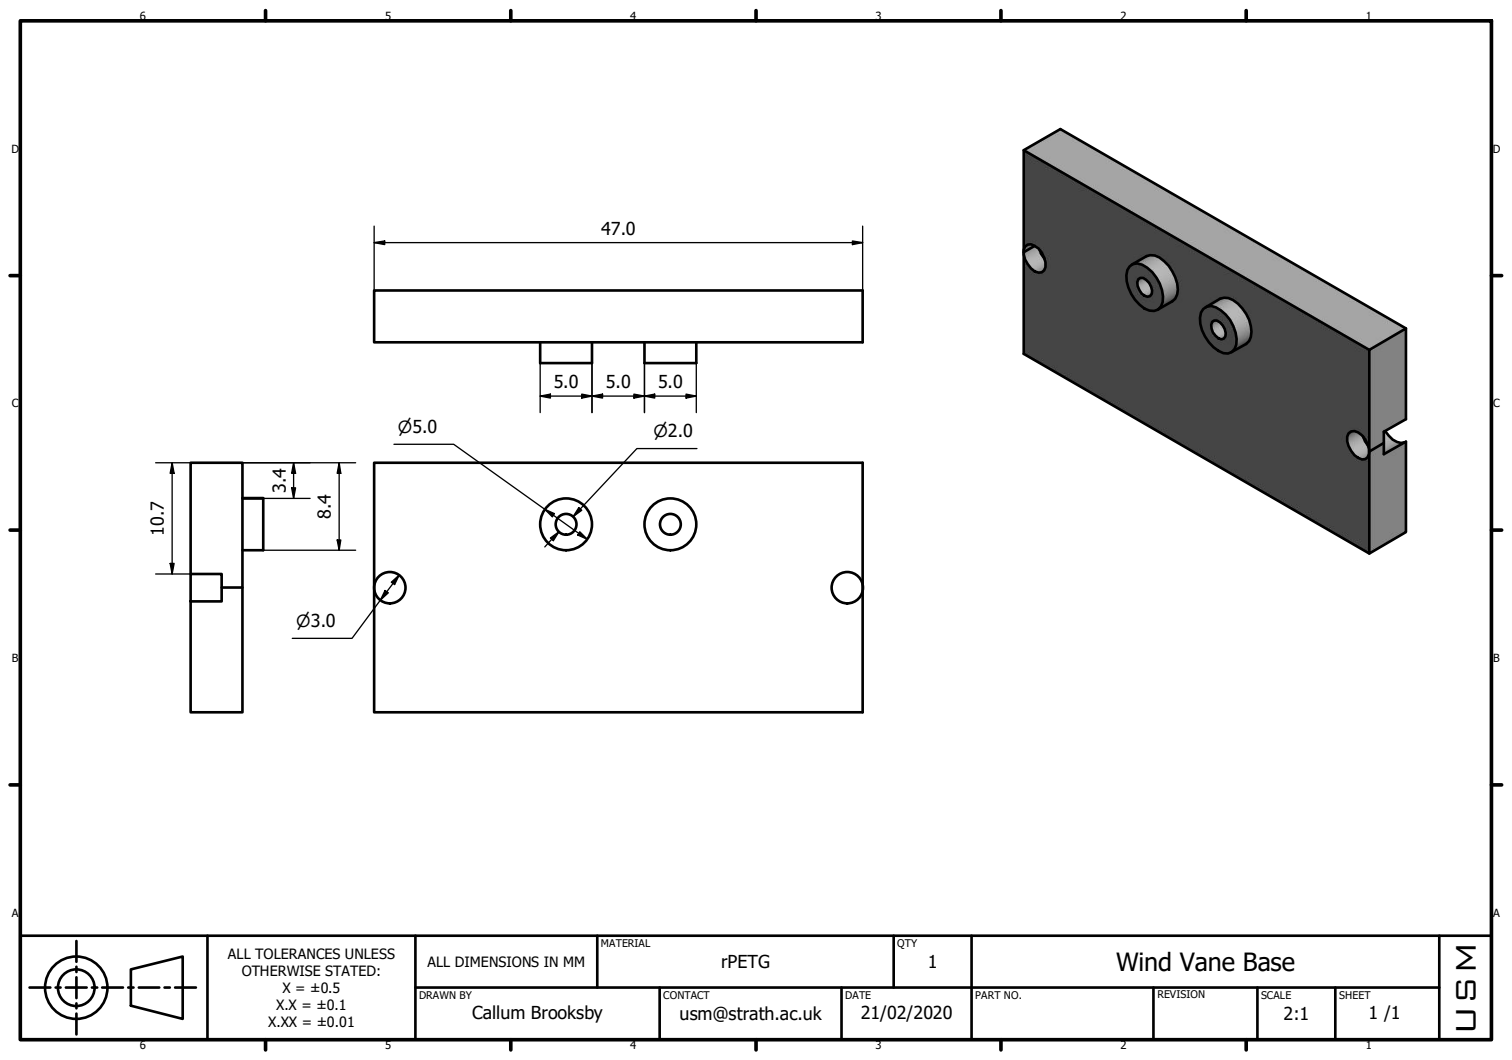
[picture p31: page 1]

ALL TOLERANCES UNLESS OTHERWISE STATED: X = ±0.5 X.X = ±0.1 X.XX = ±0.01 | ALL DIMENSIONS IN MM | MATERIAL rPETG | QTY 1 | Wind Vane Base | M

DRAWN BY Callum Brooksby | CONTACT usm@strath.ac.uk | DATE 21/02/2020 | PART NO. | REVISION | SCALE 2:1 | SHEET 1 /1

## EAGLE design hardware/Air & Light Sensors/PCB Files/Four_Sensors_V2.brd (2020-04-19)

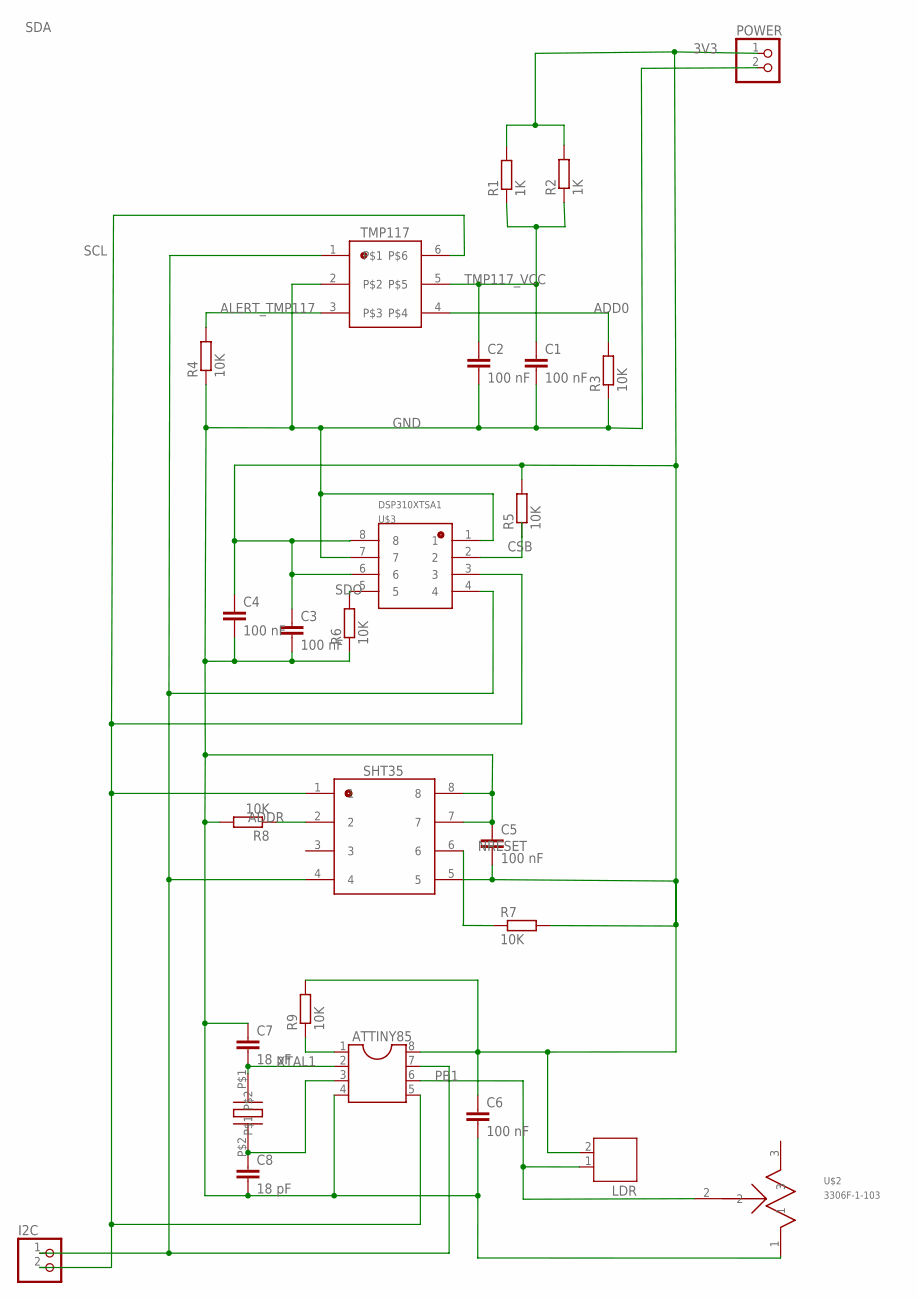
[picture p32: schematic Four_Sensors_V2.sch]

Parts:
ATTINY85: DIL8; DIL08
C1, C2, C3, C4, C5, C6: 100 nF; C0603
C7, C8: 18 pF; C0805
I2C: PINHD-1X2; 1X02
LDR: JST-PH2
POWER: PINHD-1X2; 1X02
R1, R2: 1K; R1206
R3, R4, R5, R6, R7, R8, R9: 10K; R0805
SHT35: SHT35
TMP117: TMP117
U$1: QCL16.0000F18B23B
U$2: 3306F-1-103
U$3: DSP310XTSA1

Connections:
3V3: ATTINY85.8, C3.1, C4.1, C5.2, C6.1, LDR.2, POWER.1, R1.2, R2.2, R5.2, R7.2, R9.2, SHT35.5, U$3.6, U$3.8
ADD0: R3.2, TMP117.4
ADDR: R8.1, SHT35.2
ALERT_TMP117: R4.2, TMP117.3
CSB: R5.1, U$3.2
GND: ATTINY85.4, C1.2, C2.2, C3.2, C4.2, C5.1, C6.2, C7.1, C8.2, POWER.2, R3.1, R4.1, R6.1, R8.2, SHT35.7, SHT35.8, TMP117.2, U$2.1, U$3.1, U$3.7
NRESET: R7.1, SHT35.6
PB1: ATTINY85.6, LDR.1, U$2.2
PB5: ATTINY85.1, R9.1
SCL: ATTINY85.7, I2C.1, SHT35.4, TMP117.1, U$3.4
SDA: ATTINY85.5, I2C.2, SHT35.1, TMP117.6, U$3.3
SDO: R6.2, U$3.5
TMP117_VCC: C1.1, C2.1, R1.1, R2.1, TMP117.5
XTAL1: ATTINY85.2, C7.2, U$1.P$1
XTAL2: ATTINY85.3, C8.1, U$1.P$2

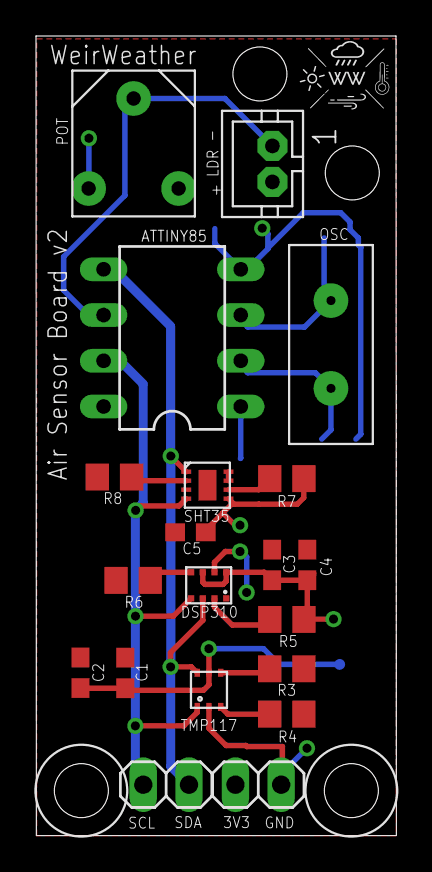
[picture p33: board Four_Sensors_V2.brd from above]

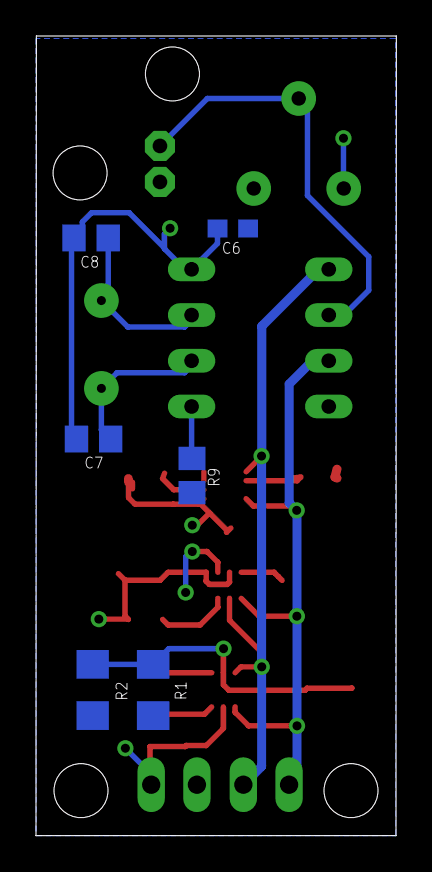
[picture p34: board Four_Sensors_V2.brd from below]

Board: 2 copper layers, 20.0 x 44.4 mm, 26 parts (6 on the bottom side), 15 nets.

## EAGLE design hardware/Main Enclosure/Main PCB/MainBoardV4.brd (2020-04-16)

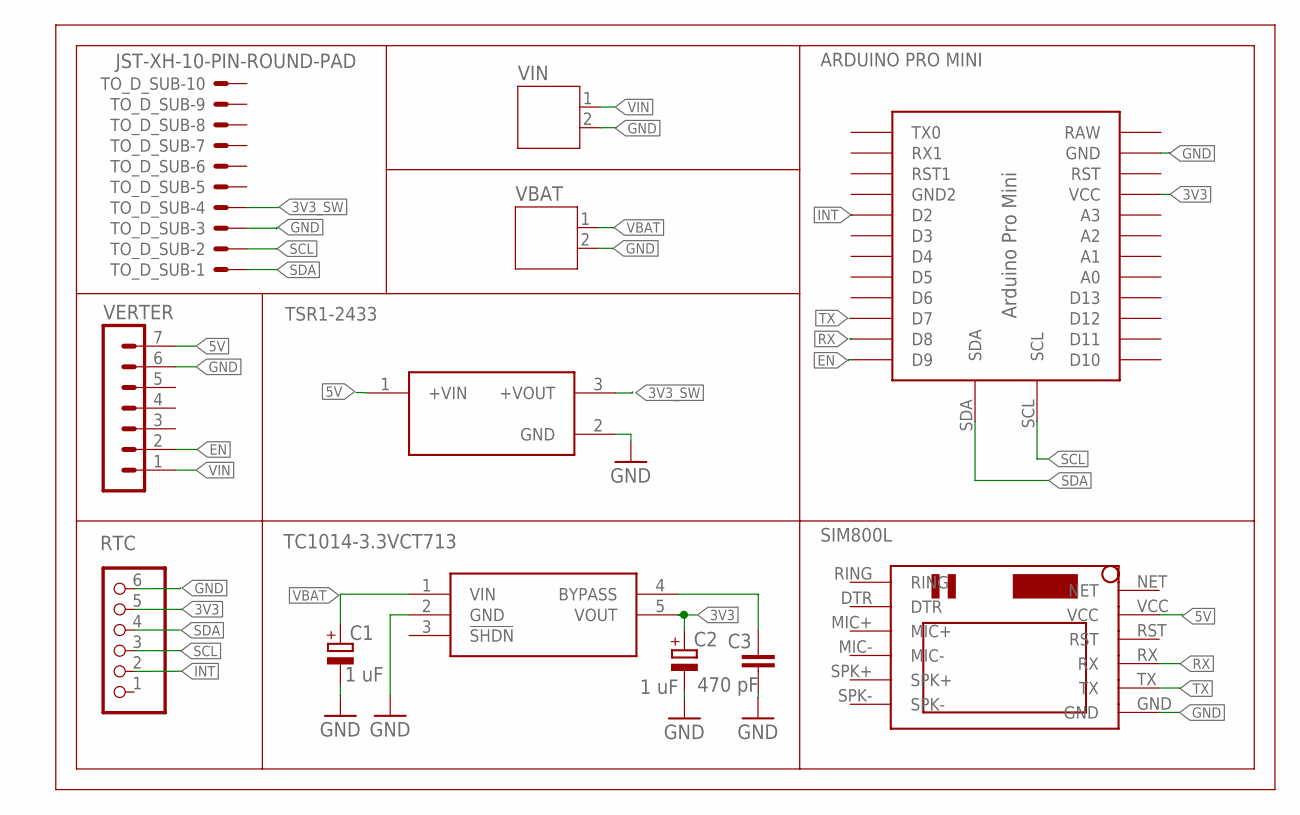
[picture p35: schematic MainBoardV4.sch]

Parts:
C1, C2: 1 uF; B/3528-21R
C3: 470 pF; C1206
RTC: PINHD-1X6; 1X06
TO_D_SUB: JST-XH-10-PIN-ROUND-PAD; JST-XH-10-PACKAGE-ROUND-PAD
TSR1-2433: TSR_1-2433; CONV_TSR_1-2433
U1: TC1014-3.3VCT713; SOT95P270X130-5N
U$1: SIM800LMODULE
U$2: ABK-PRO-MINI
VBAT: JST-PH2
VERTER: MA07-1
VIN: JST-PH2

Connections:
3V3: C2.+, RTC.5, U1.5 (VOUT), U$2.VCC
3V3_SW: TO_D_SUB.4, TSR1-2433.3 (+VOUT)
5V: TSR1-2433.1 (+VIN), U$1.VCC, VERTER.7
EN: U$2.D9, VERTER.2
GND: C1.-, C2.-, C3.1, RTC.6, TO_D_SUB.3, TSR1-2433.2 (GND), U1.2 (GND), U$1.GND, U$2.GND, VBAT.2, VERTER.6, VIN.2
INT: RTC.2, U$2.D2
unnamed: C3.2, U1.4 (BYPASS)
RX: U$1.RX, U$2.D8
SCL: RTC.3, TO_D_SUB.2, U$2.SCL
SDA: RTC.4, TO_D_SUB.1, U$2.SDA
TX: U$1.TX, U$2.D7
VBAT: C1.+, U1.1 (VIN), VBAT.1
VIN: VERTER.1, VIN.1

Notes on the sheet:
ARDUINO PRO MINI
SIM800L

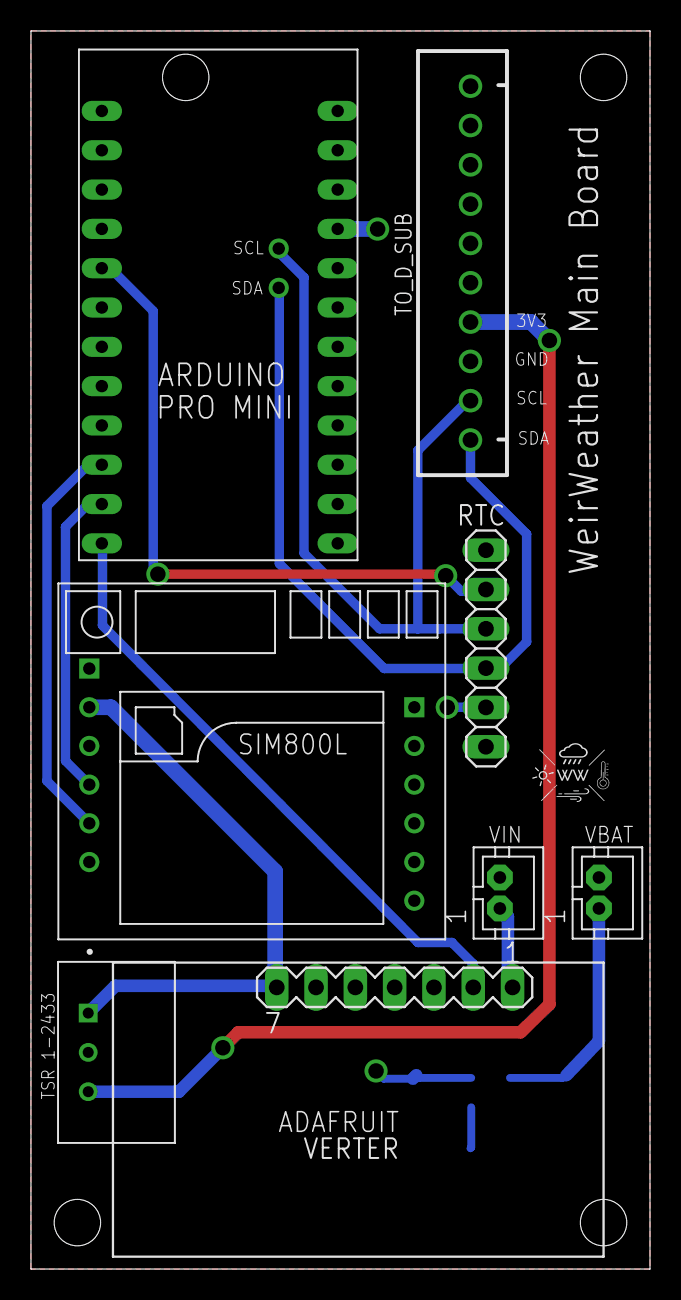
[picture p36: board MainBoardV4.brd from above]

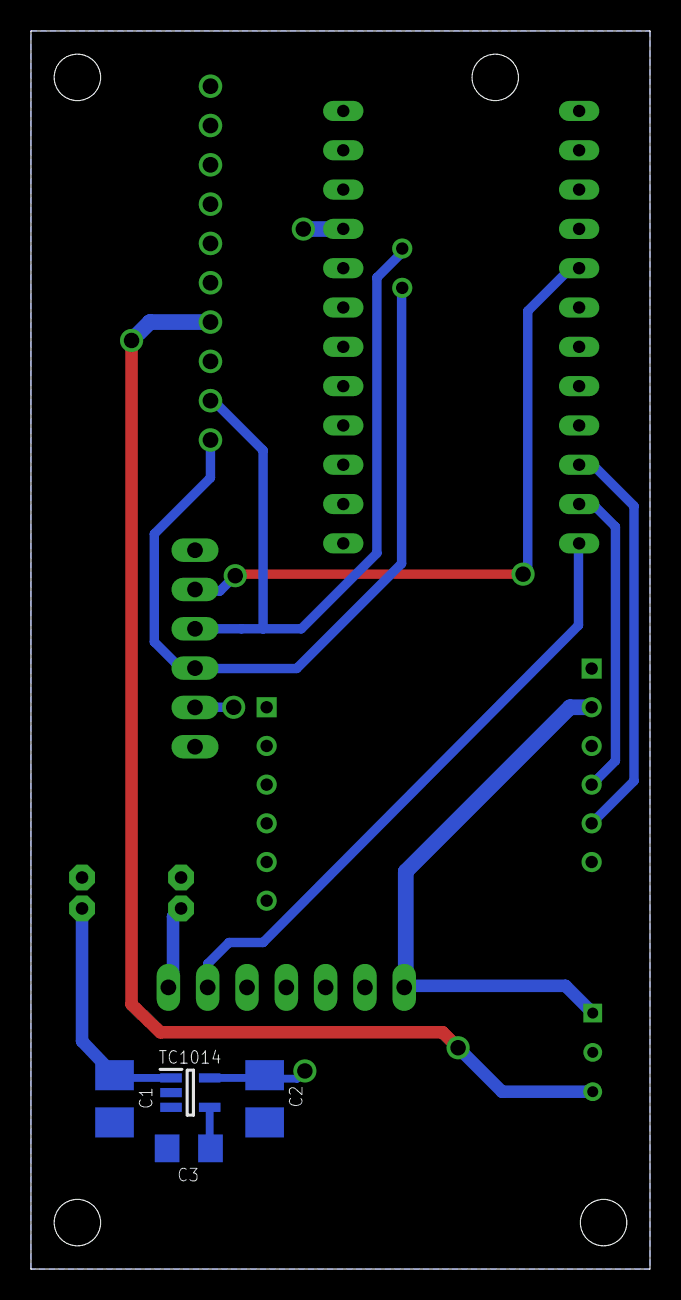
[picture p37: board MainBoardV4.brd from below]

Board: 2 copper layers, 40.0 x 80.0 mm, 12 parts (4 on the bottom side), 13 nets.

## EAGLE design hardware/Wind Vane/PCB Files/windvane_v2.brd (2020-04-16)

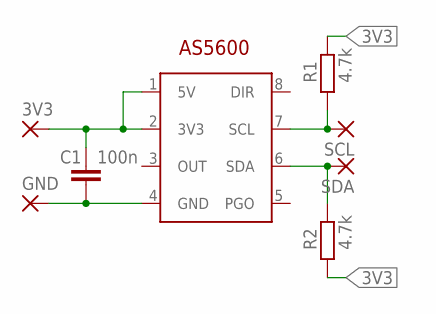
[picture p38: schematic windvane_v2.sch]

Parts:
3V3: 1,6/0,8
C1: 100n; C1206
GND: 1,6/0,8
R1, R2: 4.7k; R1206
SCL: 1,6/0,8
SDA: 1,6/0,8
U$1: AS5600; SOIC127P600X175-8N

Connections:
3V3: 3V3.1, C1.1, R1.2, R2.1, U$1.1 (5V), U$1.2 (3V3)
GND: C1.2, GND.1, U$1.4 (GND)
SCL: R1.1, SCL.1, U$1.7 (SCL)
SDA: R2.2, SDA.1, U$1.6 (SDA)

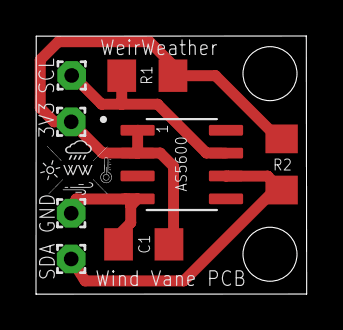
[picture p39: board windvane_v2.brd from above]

Board: 2 copper layers, 15.0 x 14.3 mm, 8 parts (0 on the bottom side), 4 nets.

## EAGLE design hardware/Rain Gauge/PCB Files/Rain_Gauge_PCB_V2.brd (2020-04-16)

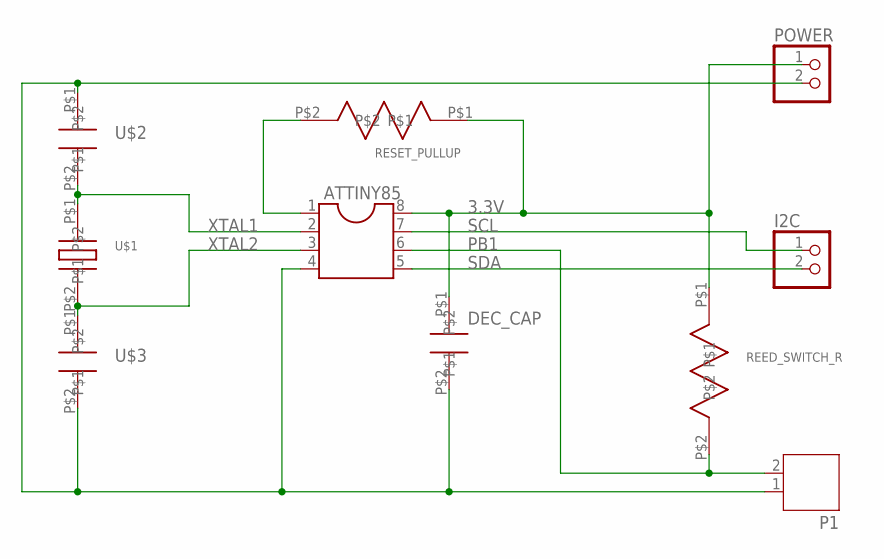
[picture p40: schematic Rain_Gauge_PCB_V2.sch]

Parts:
ATTINY85: DIL8; DIL08
DEC_CAP: 0603YC104KAZ2A
I2C: PINHD-1X2; 1X02
P1: JST-PH2
POWER: PINHD-1X2; 1X02
REED_SWITCH_R: RK73B2ATTD103J
RESET_PULLUP: RK73B2ATTD103J
U$1: QCL16.0000F18B23B
U$2, U$3: C0805C180J5GACTU

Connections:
3.3V: ATTINY85.8, DEC_CAP.P$1, POWER.1, REED_SWITCH_R.P$1, RESET_PULLUP.P$1
GND: ATTINY85.4, DEC_CAP.P$2, P1.1, POWER.2, U$2.P$1, U$3.P$2
PB1: ATTINY85.6, P1.2, REED_SWITCH_R.P$2
RESET: ATTINY85.1, RESET_PULLUP.P$2
SCL: ATTINY85.7, I2C.1
SDA: ATTINY85.5, I2C.2
XTAL1: ATTINY85.2, U$1.P$1, U$2.P$2
XTAL2: ATTINY85.3, U$1.P$2, U$3.P$1

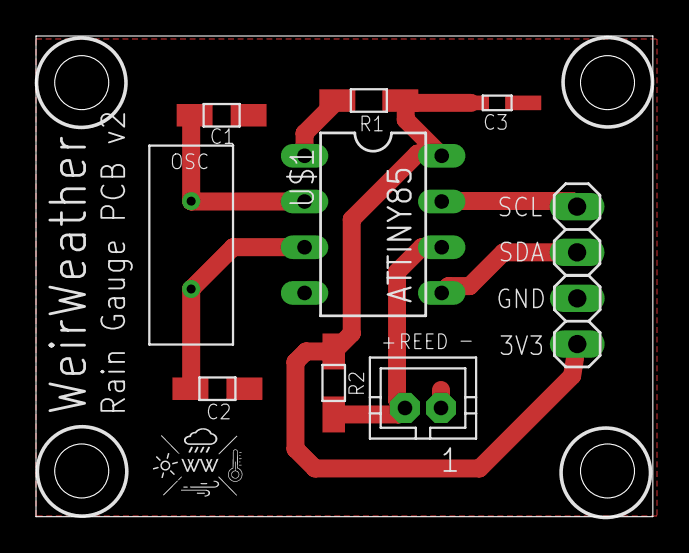
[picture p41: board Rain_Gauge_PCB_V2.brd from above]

Board: 2 copper layers, 34.3 x 26.7 mm, 10 parts (0 on the bottom side), 8 nets.

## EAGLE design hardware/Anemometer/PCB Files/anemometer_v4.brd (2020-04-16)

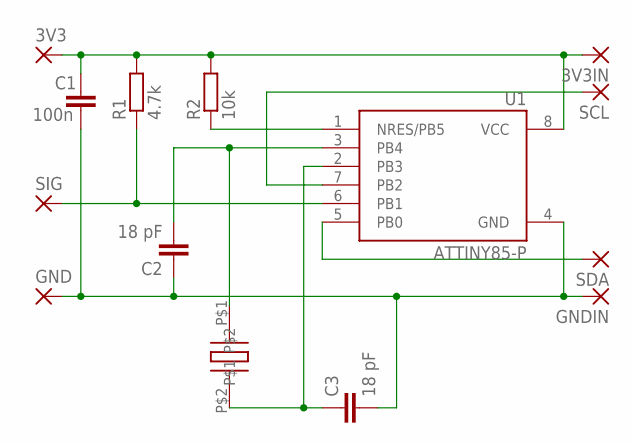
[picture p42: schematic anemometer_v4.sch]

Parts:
3V3, 3V3IN: 1,6/0,9
C1: 100n; C1206
C2, C3: 18 pF; C0805
GND: 1,6/0,9
GNDIN: 1,6/0,9
R1: 4.7k; R1206
R2: 10k; R0805
SCL: 1,6/0,9
SDA: 1,6/0,9
SIG: 1,6/0,9
U1: ATTINY85-P; PDIP08_300MIL
U$1: QCL16.0000F18B23B

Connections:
3V3: 3V3.1, 3V3IN.1, C1.1, R1.2, R2.2, U1.8 (VCC)
GND: C1.2, C2.1, C3.2, GND.1, GNDIN.1, U1.4 (GND)
unnamed: SDA.1, U1.5 (PB0)
unnamed: SCL.1, U1.7 (PB2)
unnamed: R1.1, SIG.1, U1.6 (PB1)
unnamed: C2.2, U1.3 (PB4), U$1.P$1
unnamed: C3.1, U1.2 (PB3), U$1.P$2
unnamed: R2.1, U1.1 (NRES/PB5)

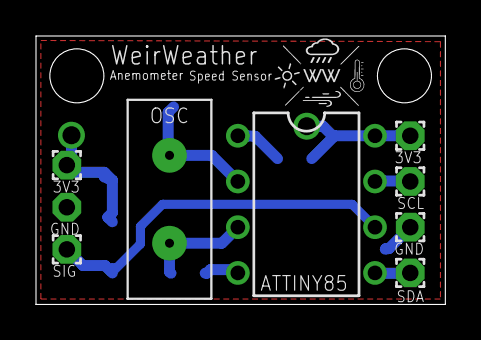
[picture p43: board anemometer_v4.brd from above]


Board: 2 copper layers, 22.7 x 14.9 mm, 14 parts (6 on the bottom side), 8 nets.

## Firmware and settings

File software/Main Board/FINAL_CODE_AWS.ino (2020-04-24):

#include <SoftwareSerial.h>
#include <Wire.h>
#include <RTClibExtended.h>
#include <LowPower.h>
#include <avr/sleep.h>
#include <Adafruit_Sensor.h>
#include <Adafruit_BME280.h>
#include <Wire.h>
#include "Seeed_SHT35.h"
#include <Dps310.h>

#define DEBUG 1                                   // Comment to exclude debug code to be uploaded
// Sensor Variables
// Rain Gauge
uint8_t rain_gauge_ADDR = 0x04;                   // Rain gauge slave I2C address
float mm_per_h = 0.0;                             // Rain intensity [mm/h]
float daily_rain = 0.0;                           // Daily rain ammount [mm]

// TMP117
const int TMP117_Address = 0x48;
const int Temp_Reg = 0x00;
double temp;

// SHT35
SHT35 sensor(21, 0x44);
float tempH, hum;

// DPS310
Dps310 Dps310PressureSensor = Dps310();
float pressure;
uint8_t oversampling = 7;
int16_t ret;

// LDR
const int LDR_Address = 0x05;
byte bytes[2];
int ldr_value;

int AS5600_ADR = 0x36;
const int raw_ang_hi = 0x0c;
const int raw_ang_lo = 0x0d;
const int ang_hi = 0x0e;
const int ang_lo = 0x0f;
const int stat = 0x0b;
const int agc = 0x1a;
const int mag_hi = 0x1b;
const int mag_lo = 0x1c;
float Ang;

// Comms and DAQ Variables
#define DS3231_I2C_ADDRESS 0x68
Adafruit_BME280 bme; // I2C
RTC_DS3231 RTC;      //sing the DS3231 RTC
SoftwareSerial gprs(7,8);
byte goToSleepNow = 1;
int ledPin = 13;
byte ledStatus = 1;
int baud = 19200;
int count = 0;
byte s,m,h,d,mo,ms;
int y;
String msg;
String timeString;
int mins = 2;
int minCount = 1;
String data = "";
int rstCount = 0;
bool lock = 0;
int period_mins = 

void flushGPRS()
{
  while(gprs.available())
  {
    char msg = gprs.read();
  }
}

void toSerial()
{
  flushGPRS();
  delay(10);
  flushGPRS();
}

void sendGPRS2(char* msg, int delayMs = 400)
{
    flushGPRS();
    gprs.println(msg);
    delay(delayMs);
    while (gprs.available())
    {
      data += gprs.readString();
    }
    delay(10);
    while (gprs.available())
    {
      data += gprs.readString();
    }
    flushGPRS();
    if((!(data.indexOf("1,200") >= 0)) && rstCount < 4)
    {
      data = "";
      rstCount += 1;
      connectGPRS();
      getRTCTime();
      readDataWW();
      sendPost();
    }
    else
    {
      data = "";
      rstCount = 0; 
      return;
    }
}

void sendGPRS(char* msg, int delayMs = 400)
{
  gprs.println(msg);
  toSerial();
  delay(delayMs);
  toSerial();
}

void wakeupGPRS()
{
  flushGPRS();
  delay(10);
  gprs.println("AT");
  gprs.println("AT+CSCLK=0");
  delay(100);
  flushGPRS();
}

void connectGPRS()
{
  // Set up GPRS Connection
  sendGPRS("AT+SAPBR=3,1,\"Contype\",\"GPRS\"");
  // Set the APN
  sendGPRS("AT+SAPBR=3,1,\"APN\",\"everywhere\"");
  // Enable GPRS
  sendGPRS("AT+SAPBR=1,1",750);
  sendGPRS("AT+SAPBR=2,1",750);
  delay(50);
  toSerial();
}

void readDataWW()
{
  msg += "dateTime=";
  msg += y;  msg += '-';
  if(mo<10) {msg += '0';}
  msg += mo; msg += '-';
  if(d<10)  {msg += '0';}
  msg += d;  msg += " ";
 
  if(h<10)  {msg += '0';}
  msg += h;  msg += ':';
  if(m<10)  {msg += '0';}
  msg += m;  msg += ':';
  if(s<10)  {msg += '0';}
  
  msg += s;  msg += '&';
  
  // Read and Store Sensor Values
  readRainGauge();
  ReadTempSensor();
  readHumidity();
  readPressure();
  readLDR();
  readWindVane();
  

  msg += "temperature=";
  msg += temp;
  msg += "&";
  msg += "humidity=";
  msg += hum;
  msg += "&";
  msg += "airPressure=";
  msg +=  pressure;
  msg += "&";
  msg += "windDirection=";
  msg +=  Ang-3;
  msg += "&";
  msg += "windSpeed=";
  msg += windSpeed;
  msg += "&";
  msg += "solarRadiation=";
  msg +=  ldr_value;
  msg += "&";
  msg += "rainLevel=";
  msg +=  mm_per_h;
  
  
  // Testing values 
  /*
  msg += "temperature=";
  msg += bme.readTemperature();
  msg += "&";
  msg += "humidity=";
  msg += bme.readHumidity();
  msg += "&";
  msg += "airPressure=";
  msg += bme.readPressure() / 100.0F;
  msg += "&";
  msg += "windDirection=270&";
  msg += "windSpeed=10&";
  msg += "solarRadiation=1&";
  msg += "rainLevel=7";*/
  
  msg += "&bootCount=";
  msg += count;
  delay(10);
}

void sendPost()
{
   delay(100);
   // Initialize HTTP Service
   sendGPRS("AT+HTTPINIT");
   // Set URL to POST Data to
   sendGPRS("AT+HTTPPARA=\"CID\",1");
   sendGPRS("AT+HTTPPARA=\"URL\",\"http://82.27.165.48/Weir-Weather/php/Data_Input.php\"",750);
   toSerial();
   sendGPRS("AT+HTTPPARA=\"CONTENT\",\"application/x-www-form-urlencoded\"",750);
   // Set Data Length & Max Send Time in ms
   sendGPRS("AT+HTTPDATA=155,1000");
   // Send Data
   flushGPRS();
   char c[msg.length()+1];
   strcpy(c,msg.c_str());
   sendGPRS(c,1000);
   msg = "";
   // Send HTTP POST Request
   flushGPRS();
   sendGPRS2("AT+HTTPACTION=1",4000);
   sendGPRS("AT+HTTPREAD",1250);
   sendGPRS("AT+HTTPTERM",300);
}

void closeGPRS()
{ 
  sendGPRS("AT+SAPBR=0,1",750);
  delay(50);
  toSerial();
}

void readAndTransmitData()
{
  connectGPRS();
  getRTCTime();
  readDataWW();
  sendPost();
  count++;
}

void getRTCTime()
{
  DateTime time = RTC.now();
  h = time.hour();
  m = time.minute();
  s = time.second();
  d = time.day();
  mo = time.month();
  y = time.year();
}

void startComms()
{
  Wire.begin();
  gprs.begin(baud);
  bme.begin(0x76);
  RTC.begin();
  delay(50);
}

void wakeUp()        // here the interrupt is handled after wakeup
{
  if(!lock)
  {
    delay(5);
    detachInterrupt(0);
    sleep_disable();
    delay(5);
  }
}

void readRainGauge()
{
  byte bytes_mmph[4] = {0,0,0,0};
  byte bytes_daily[4] = {0,0,0,0};
  
  Wire.requestFrom(rain_gauge_ADDR, 8);           // request 8 bytes from slave device address
 
  while(Wire.available())
  {
    // Receive mm/h
    for(int n = 0; n < 4; n++)
    {
      bytes_mmph[n] = Wire.read();                // receive a byte as character
    }

    // Receive daily amount
    for(int n = 0; n < 4; n++)
    {
      bytes_daily[n] = Wire.read();
    }
  }

  // Convert bytes into floats
  memcpy(&mm_per_h, &bytes_mmph, 4);              
  memcpy(&daily_rain, &bytes_daily, 4);
}

double ReadTempSensor()
{
  // Data array to store 2-bytes from I2C line
  uint8_t data[2];
  //  Combination of 2-byte data into 16-bit data
  uint16_t datac;

  // Points to device and begins transmission
  Wire.beginTransmission(TMP117_Address);
  // Points to temperature register to read/write data
  Wire.write(Temp_Reg);
  // Ends data transfer and transmits data from register
  Wire.endTransmission();

  // Dealy to allow sufficient conversion time
  delayMillis(10);

  // Request 2-bite temperature from device
  Wire.requestFrom(TMP117_Address, 2);

  // Check if the data received matches the requested 2-bytes
  if(Wire.available() <= 2)
  {
    // Store each byte of data from temperature register
    data[0] = Wire.read();
    data[1] = Wire.read();

    // Combine data to make 16-bit binary number
    datac = ((data[0] << 8) | data[1]);

    // Convert to Celcius (7.8125 mC resolution) and return
    return datac * 0.0078125;
  }
}

void readHumidity()
{
  u16 value = 0;
  u8 data[6] = {0};
  if (NO_ERROR != sensor.read_meas_data_single_shot(HIGH_REP_WITH_STRCH, &tempH, &hum)) {
      #ifdef DEBUG
      Serial.println("read temp failed!");
      Serial.println("   ");
      Serial.println("   ");
      Serial.println("   ");
      #endif
  }
}
void readPressure()
{
  ret = Dps310PressureSensor.measurePressureOnce(pressure, oversampling);
  if (ret != 0)
  {
    #ifdef DEBUG
    //Something went wrong.
    //Look at the library code for more information about return codes
    Serial.print("FAIL! ret = ");
    Serial.println(ret);
    #endif
  }
}

void readLDR()
{
  Wire.requestFrom(LDR_Address, 2);  // request 2 bytes from slave device address 5

  while(Wire.available()) // slave may send less than requested
  {
    for(int n = 0; n < 2; n++)
    {
      bytes[n] = Wire.read(); // receive a byte as character
    }
  }
  memcpy(&ldr_value, &bytes, 2);
}


void readWindVane()
{
  // Read Raw Angle Low Byte
   Wire.beginTransmission(AS5600_ADR);
   Wire.write(raw_ang_lo);
   Wire.endTransmission();
   Wire.requestFrom(AS5600_ADR, 1);
   while(Wire.available() == 0);
   int lo_raw = Wire.read();
   // Read Raw Angle High Byte
   Wire.beginTransmission(AS5600_ADR);
   Wire.write(raw_ang_hi);
   Wire.endTransmission();
   Wire.requestFrom(AS5600_ADR, 1);
   while(Wire.available() == 0);
   word hi_raw = Wire.read();
   hi_raw = hi_raw << 8; //shift raw angle hi 8 left
   hi_raw = hi_raw | lo_raw; //AND high and low raw angle value
   //**********************************************************
   // Read Angle Low Byte
   Wire.beginTransmission(AS5600_ADR);
   Wire.write(ang_lo);
   Wire.endTransmission();
   Wire.requestFrom(AS5600_ADR, 1);
   while(Wire.available() == 0);
   int lo_ang = Wire.read();
   //Read Angle High Byte
   Wire.beginTransmission(AS5600_ADR);
   Wire.write(ang_hi);
   Wire.endTransmission();
   Wire.requestFrom(AS5600_ADR, 1);
   while(Wire.available() == 0);
   word hi_ang = Wire.read();
   hi_ang = hi_ang << 8;
   hi_ang = hi_ang | lo_ang;
   //**************************************************
   //Read Magnitude High Byte
   Wire.beginTransmission(AS5600_ADR);
   Wire.write(mag_hi);
   Wire.endTransmission();
   Wire.requestFrom(AS5600_ADR, 1);
   while(Wire.available() == 0);
   word hi_mag = Wire.read();
   //Read Magnitude Low Byte
   Wire.beginTransmission(AS5600_ADR);
   Wire.write(mag_lo);
   Wire.endTransmission();
   Wire.requestFrom(AS5600_ADR, 1);
   while(Wire.available() == 0);
   word lo_mag = Wire.read();
   hi_mag = hi_mag << 8;
   hi_mag = hi_mag | lo_mag;
   //**************************************************
   //Read AGC
   Wire.beginTransmission(AS5600_ADR);
   Wire.write(agc);
   Wire.endTransmission();
   Wire.requestFrom(AS5600_ADR, 1);
   while(Wire.available() == 0);
   int agc_val = Wire.read();
   //***************************************************
   // Read Status Bits
   Wire.beginTransmission(AS5600_ADR);
   Wire.write(stat);
   Wire.endTransmission();
   Wire.requestFrom(AS5600_ADR, 1);
   while(Wire.available() == 0);
   int stat_val = Wire.read();
   stat_val = stat_val & 0xa0; //Mask off all unnecessary bits
   Ang = hi_ang * 0.0879;
}
// Function to replace delay()
void delayMillis(uint32_t ms)
{
  uint32_t start_time = millis();

  while(1)
  {
    if((millis() - start_time) > ms)
    {
      return;
    }
  }
}

void sleepMCU()
{
  delay(10);
  attachInterrupt(0, wakeUp, FALLING);
  RTC.setAlarm(ALM1_MATCH_SECONDS, 0, 0, 0, 0);
  RTC.alarmInterrupt(1, true); //set alarm1
  digitalWrite(9,LOW);
  lock = 0;
  delay(1000);
  LowPower.powerDown(SLEEP_FOREVER, ADC_OFF, BOD_OFF); 

  // Continue only every 'period_mins' minutes
  // Return every other minute
  if(minCount == period_mins){minCount = 1;}
  else{minCount++; return;}
  lock = 1;
  delay(50);
  digitalWrite(9,HIGH);
  delay(30000);
  startComms();
  readAndTransmitData();
  delay(50);
}

void setup() {
  // Begin Serial & I2C Communication
  startComms();
  //RTC.adjust(DateTime(__DATE__, __TIME__));
  // Set up RTC Alarm Every Minute & Interrupt Pin
  RTC.armAlarm(1, false);
  RTC.clearAlarm(1);
  RTC.alarmInterrupt(1, false);
  RTC.writeSqwPinMode(DS3231_OFF);
  RTC.setAlarm(ALM1_MATCH_SECONDS, 0, 0, 0, 0);
  RTC.alarmInterrupt(1, true); // Set RTC alarm1
  pinMode(2,INPUT_PULLUP); // Enable interrupt pin
  pinMode(9,OUTPUT); // Enable digital output
  digitalWrite(9,LOW); // Enable Verter output
}

void loop() {sleepMCU();}

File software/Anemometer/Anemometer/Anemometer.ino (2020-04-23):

#include <TinyWireS.h>

#define INTERRUPT_PIN PCINT1              // PB1
#define HALL_PIN PB1                      // Interrupt pin: PB1

#define I2C_SLAVE_ADDRESS 0x06            // Address of the slave

const int magnets = 4;                    // Number of pulses/magnets per revolution
int hall_count = 0;
float start_time;
float rps;
float omega;
const float radius = 0.04;                // Anemometer radius [m]
float v;
float past_v[25];                         // Array dimension must be equal to av_time
const int av_time = 25;                   // Average wind speed over this period of time [s]
float sum = 0;
float average_v;

volatile bool reading = 0;
volatile bool wait = 1;

byte bytes[4];

void setup()
{
    cli();                                // Disable interrupts during setup
    
    PCMSK |= (1 << INTERRUPT_PIN);        // Enable interrupt handler (ISR) for our chosen interrupt pin (PCINT1/PB1/pin 6)
    GIMSK |= (1 << PCIE);                 // Enable PCINT interrupt in the general interrupt mask
    pinMode(HALL_PIN, INPUT_PULLUP);      // Set our interrupt pin as input with a pullup to keep it stable
    
    // Timer configuration
    TCCR1 |= (1 << CTC1);                 // clear timer on compare match
    TCCR1 = 0x0F;                         //clock prescaler 16384 (CLK = 16 MHz => (16*10e6/16384)^-1 = 1.024 ms)
    OCR1C = 20;                           // compare match value (20.48 ms)
    TIMSK |= (1 << OCIE1A);               // enable compare match interrupt
    
    sei();                                // enable interrupts
    
    TinyWireS.begin(I2C_SLAVE_ADDRESS);   // join i2c network
    TinyWireS.onRequest(requestEvent);

    // Initialise past velocity array
    for (int n = 0; n < av_time; n++)
    {
      past_v[n] = 0.0;
    }

    start_time = millis();
}

void loop() 
{
  TinyWireS_stop_check();

  // Check wind speed every second
  if (millis() - start_time > 1000)
  {
    // Calculate wind speed
    rps = (hall_count / magnets);       // Revolution per second
    omega = rps * 2 * PI;               // Angular velocity [rad/s]
    v = omega * radius;                 // Wind velocity [m/s]

    // Push arry one position back and save the latest measuremnt in the last position
    sum = 0;
    for (int n = 0; n < av_time; n++)
    {
      if (n == (av_time - 1))
      {
        past_v[n] = v;
      }
      else
      {
        past_v[n] = past_v[n + 1];
      }

      sum = sum + past_v[n];
    }

    // Average array
    average_v = sum / av_time;

    // Reset counter
    hall_count = 0;

    start_time = millis();
  }
}

// Gets called when the ATtiny receives an i2c request
void requestEvent()
{   
    memcpy(&bytes, &average_v, 4);

    for(int n = 0; n < 4; n++)
    {
      TinyWireS.send(bytes[n]);
    }
}

ISR(PCINT0_vect)
{
  // Reset compare register to ensure timer gets called after 20 ms
  OCR1C = 0;
  OCR1C = 20;
  
  reading = 1;
}

ISR(TIMER1_COMPA_vect)
{
  // =========== 20 ms debouncing ===============
  if(reading == 1)
  {
    if(digitalRead(HALL_PIN) == LOW)  // Detects falling edge only
    {
      hall_count += 1;
    }
  }
  reading = 0;
}

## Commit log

2020-04-16 Rain Gauge CAD and STLs files
    [Base.stl, Collector_1_of_4.stl, Collector_2_of_4.stl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]
2020-04-16 Rain Gauge CAD and STLs update
    [Rain_Gauge.dwg, Support.stl]
2020-04-16 Rain Gauge CAD README
2020-04-16 Atmospheric sensors CAD and STLs files and README
    [PCB Holder.dwg, PCB Holder.stl, Rad_Shd_Base_V1.stl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]
2020-04-16 Atmospheric sensors README update
2020-04-18 Radiation shield CAD update
    [PCB Holder.dwg]
2020-04-18 Radiation shield support CAD update
    [Support.dwg]
2020-04-19 Radiation shield CAD files update
    [PCB Holder.dwg, Support.dwg]
2020-04-19 Rain Gauge CAD update
    [Rain_Gauge.dwg]
2020-04-19 Rain gauge BOM
    [BOM.xlsx]
2020-04-19 Rain gauge BOM update
    [BOM.xlsx]
2020-04-19 Radiation shield BOM
    [BOM.xlsx]
2020-04-21 Radiation shield BOM update
    [BOM.xlsx]
2020-04-21 BOMs renamed
    [Radiation Shield BOM.xlsx, Rain Gauge BOM.xlsx]
2020-04-21 Main enclosure BOM
    [Main Enclosure BOM.xlsx]
2020-04-21 Stucture BOM
    [Structure BOM.xlsx]
2020-04-21 Anemometer BOM
    [Anemometer BOM.xlsx]
2020-04-21 Anemometer STL files
    [Base.stl, Bottom-1.stl, Cap.stl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]
2020-04-21 Wind vane BOM
    [Wind Vane BOM.xlsx]
2020-04-21 Wind vane STL files
    [Base.stl, Bottom.stl, Lid-V2.stl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]
2020-04-22 BOM update
    [Anemometer BOM.xlsx, Main Enclosure BOM.xlsx, Radiation Shield BOM.xlsx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]
2020-04-23 Structure BOM update
    [Structure BOM.xlsx]
